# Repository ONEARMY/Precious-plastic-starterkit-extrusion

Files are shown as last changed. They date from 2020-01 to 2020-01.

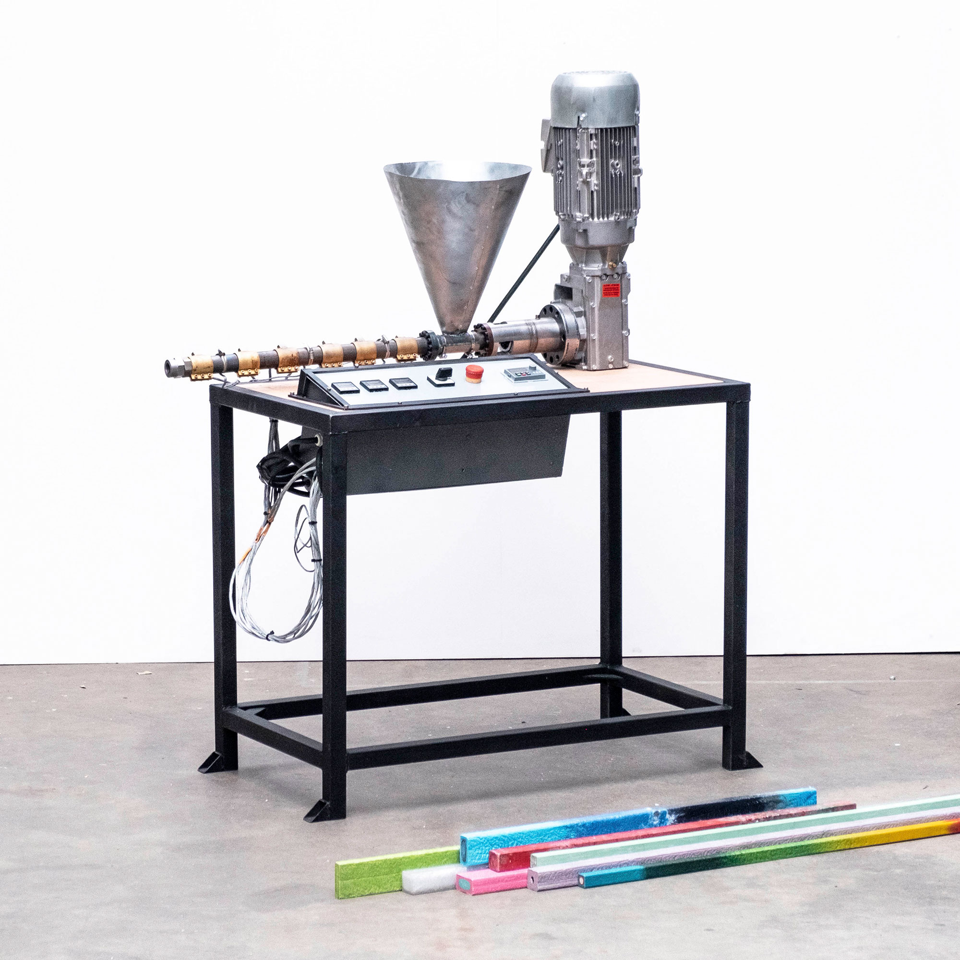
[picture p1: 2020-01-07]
3. Build the machine/Extrusion-Pro-image.jpg

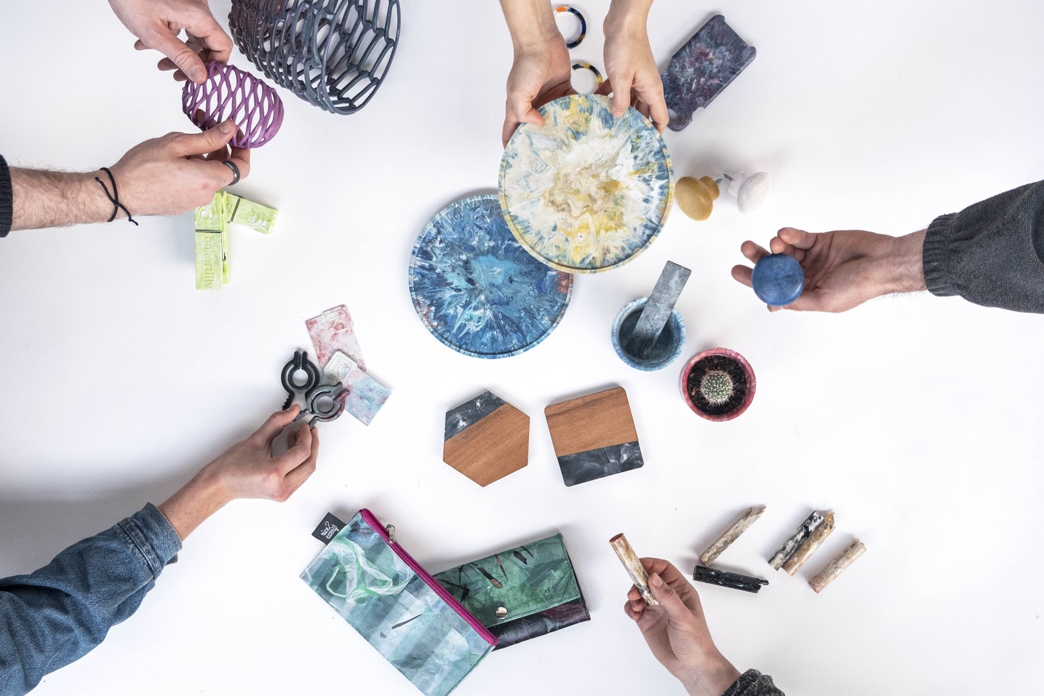
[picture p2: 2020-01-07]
6. Run your Workspace/3. Share/2. Project Images/Products/Products.jpg

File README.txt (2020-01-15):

# Starterkit - Extrusion Workspace V1.1

YEAH, you made it into a starter-kit!
Start with the 0. Start folder.. read the introduction text and make sure to watch the videos from our website.

If you have any questions visit our community platform or Discord
https://community.preciousplastic.com/
https://discordapp.com/invite/rnx7m4t

Good luck!!

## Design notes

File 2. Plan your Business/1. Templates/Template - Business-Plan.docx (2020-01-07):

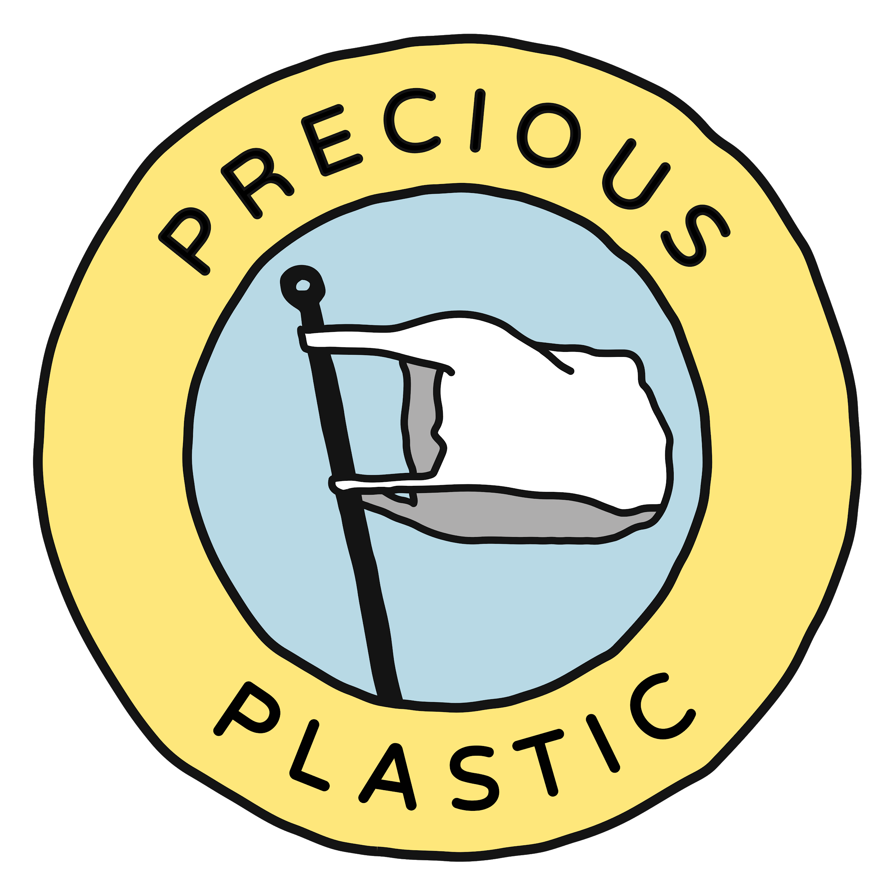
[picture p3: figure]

Your Logo and Business Name Here 👆

# Contact Details

Contact name:

Address:

City:

Zip:

Email:

Phone Number:

Website URL :

# Outline

1. Executive summary
2. Mission
3. Team
4. Market Analysis
  a. Product and Services
  b. Target Groups
  c. Engagement
  d. Sales Channels
5. Operations
  a. Key Resources
  b. Key Activities
  c. Running Costs
  d. Collaborators
6. Impact Measures
  a. Community
  b. Planet
  c. Income Streams
7. Financials
8. Legal Structure
9. Appendix

# 1. Executive Summary

This is your chance to quickly make your argument of what the problem is and how your business is going to solve it. This section shouldn’t be more than a couple paragraphs. Quickly cover the problem, your unique solution, who you’re targeting, and what your impact will be. It’s best to write this section after you’ve completed the whole business plan.

# 2. Mission

What’s the problem?

It’s best to start off describing what problem you’re solving. If your audience might need some education about the plastic waste problem - here’s your chance. What part or aspect of the plastic waste problem are you focusing on? You can set some context about the global plastic waste issue, but make sure to drill down to your national and local level as well. Try to be specific and stress why this is such a big problem facing the planet and your local community. Show your passion for solving this problem. This section will set the stage for the whole story told throughout the plan.

What’s your solution?

Next briefly cover how your solution addresses this problem. For example, if you write about how the plastic waste problem is due to a lifestyle issue, maybe you’re solution is focused on educating people because it addresses the root cause of the problem.

What’s your mission statement?

Look back on your mission that you filled out in the action plan. How can you elaborate to explain it to your reader?

What’s your vision?

Once you have explained your mission - write just a few sentences about your vision. What kind of world do you envision, and what do you envision for your organization?

# 3. Team

Fill in some basic information about your team to show who’s involved and what relevant skills and experience they have to the business.

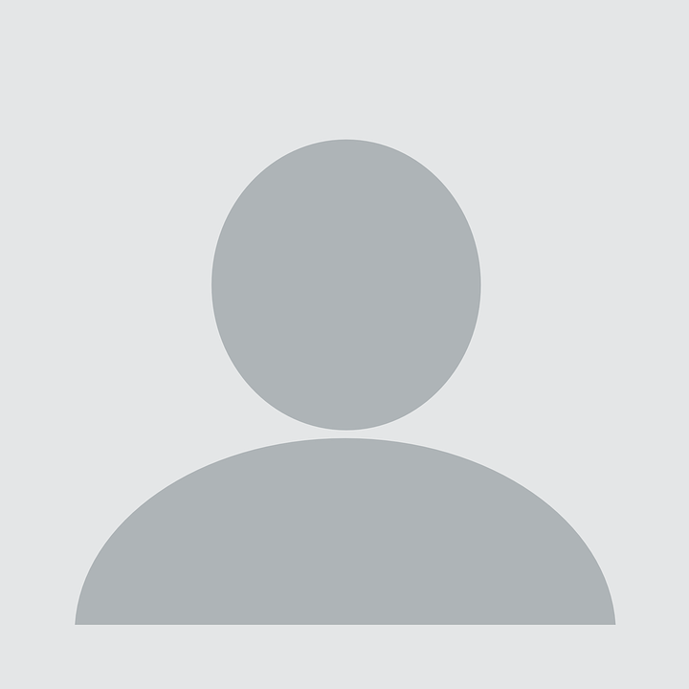
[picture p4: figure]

Name: Role: Experience: | Name: Role: Experience: | Name: Role: Experience:

# 4. Market Analysis

The market analysis section (broken down by the right side of the action plan), is where you will describe how the market is currently performing in your area of interest, how you plan to enter the market, what makes you different, who you are targeting, and how you will deliver your products and services to the customer.

## A. Products & Services

Product explanation

Explain that there is something missing from the market currently and what unique products or services you will offer to meet that unmet need. Write down a brief description of the products and services you are planning to make and include some pictures if possible. Include the price range they will be in and how this compares to similar products/services. If you have any sketches or pictures of your products, you can also include them here.

Product Photos or Sketches:

Competitive advantage

It’s unlikely that your product or service is completely unique - there are businesses or organizations that are probably doing something similar. What are those businesses, what are they offering, and how are you differentiating yourself? Another way to ask this what is your competitive advantage? What are you doing that sets you apart? Describe it here.

Total Available Market

What would you estimate to be the total available market for your product or service? For example, I’m targeting the plastic waste generated in my town, and I know from my city waste department that we generate about 100 tons per month of waste plastic. That means if we were to capture 100 % of the market, we would be processing all 100 tons. If we value each ton at $10, that a $12,000 total available market per year. You should include the total available market that you’re targeting to show how big your business could potentially grow.

## B. Target Groups

Identify the groups

In this section, explain who your target customer groups are, and how many potential customers are in this group. What do you know about these groups? This is your chance to communicate your research about your customers.

Research

What research have you done to show that your target groups will be interested in your products and services? Discuss any field research that you’ve done or online research about these groups. For example, if you’re producing craft furniture from plastic waste, do some research online to see if you can find numbers on the total craft furniture market value in your country. You could also run a small survey in your area to gauge interest in your products.

If you’re targeting businesses, do you have any letters of intent or proof that they are willing to buy your product or service when you’re able to get up and running? This can be a very powerful tool for showing your business case - you already have customers lining up to buy.

## C. Engagement

Engagement is how you will engage with your target customer groups and how many people you can potentially reach with this engagement strategy. What marketing channels are you using? If you’re using social media - which platforms? What’s your engagement rollout plan? Do you intend to start with one marketing channel and then gradually expand? Communicate your marketing plan here.

## D. Sales Channels

Finally, explain what your sales channels are. Explain where and how people can buy your products/services. Explain why you chose these sales channels, and relate that back to your target groups.

Business to Business (B to B) versus Business to Consumer (B to C)

Are you focusing on business to consumer or business to business? This is an important distinction, because it will help the reader understand your business model. Business to consumer (B to C) means that you are targeting consumers directly - you will be the one selling the product or service to the end user. If you are instead focusing on business to business (B to B), that means that you’ll be selling to other businesses. For example - if you’re a machine builder that will be selling machines to new workspaces - this is a business to business model. If you are a product producer selling products directly to people through the Precious Plastic Bazar, this is an example of business to consumer.

# 5. Operations

## A. Key Resources

First explain what key resources, or the key tools, machines, people, and any other resources that are crucial for you to deliver on your mission.

Another good thing to include here is any permits or licenses that you might need from the government in order to be able to operate. Are there any safety requirements that you need to follow? What resources do you need to have available in order to do so? What about people - are there any key skill sets that you need?

Include any pictures of your workspace if it’s relevant as well.

## B. Key Tasks

Explain your key tasks - What actions and activities will you need to focus on? Show that you have a clear sense of what needs to be done. How will produce your product or service and what are the key tasks that you must do to support this core delivery. Describe your production or service delivery process in detail and how you will maintain quality. How do you and your team’s skills and experience match up with these activities?

## C. Running Costs

In this section you will describe in more detail the key running costs that you identified in the Action Plan. Doesn’t need to be very long - this is just to show that you’ve thought about the costs that are a risk to the business month after month. If you have a way to control these costs, discuss that here as well.

## D. Collaborators

Finally, write about who your key collaborators are. What people, groups and organizations will be key in helping you fulfill your mission? Say what they will add to your business, and what your current relationship is with them. Are these people you would like to collaborate with, or you’ve already started? What’s the current status? How will they help you deliver on your mission? Be specific here - show what strategic relationships that you have which will be a strategic asset to your business.

# 6. Impacts

## A. Community

Here’s your chance to write about the positive impact you will have on your community. What’s the direct impact you will have on improving the lives of real people? Link this back to your mission and vision if possible.

You can also discuss your involvement with the Precious Plastic community. Perhaps discuss how you will contribute back to the Precious Plastic open source community and share your knowledge with other Precious Plastic workspaces.

## B. Planet

The planet section is for you to discuss the positive impact you will have on the environment. Show your vision and dream about a cleaner, greener future. It’s important to think about how you will measure this as well. For many Precious Plastic businesses this will be the amount of material recycled.

## C. Income Streams

Next describe your revenue model, or how you intend to bring in money month after month. Refer back to what you wrote in the action plan - is it product sales, workshop ticket sales, machine maintenance fees, or some other revenue model? How do you intend to price your products and services? Do you have different models for different products and services? Describe each one in detail.

# 7. Financials

The financials section is where you will build holistic financial picture to argue that you can turn your idea into a financially successful business.

First, write about the investment costs that you will have to pay in order to get started. You can pull this information from the workspace calculator and paste into a table. Copy in the investment costs table from the workspace calculator and add a total value.

Investment Costs
Initial Investments | Cost
Total:

Next describe how you intend to raise the initial money you need to get started. Is this a bank loan, grants, your private money, or assistance from the local government? Describe the different forms of financial assistance that you are pursuing.

Next you should copy in the Profit & Loss statement from the workspace calculator generated on the “extras” page. The profit and loss statement shows your estimated financial outlook for the first three years of operation.

Profit and Loss Statement
| Year 1 | Year 2 | Year 3
Revenue
Cost of Sales
Net Revenue
Fixed Costs
Gross Income from Operations
Business Taxes
Net Income

The cash flow statement shows that you will have enough money on hand to meet your financial obligations throughout the first year. Grants or bank loan applications often ask for these statements.

Cash Flow Statement
Month
Money In Bank (Beginning of Month)
Initial Investment
Revenue
Total Cash In
Investment Costs
Variable Costs
Fixed Costs
Total Cash Out
Net Cash Flow
Money In Bank (End of Month)

8. Legal Structure

The legal structure section is where to describe how you’ll be organized as a legal entity, or how you’re registered with the government. Your project doesn’t need to be structured as a commercial business - could be a non-profit, association, cooperative, project within an existing business, B - corp, social business. “Business plan” is the terminology that’s often used for a plan such as this, but doesn’t mean you need to run it necessarily as a “for-profit” business. This is going to depend on your situation, and could also depend on your country - sometimes it’s easier to structure a project a certain way depending on the legal entity regulations. One or the other maybe more tax friendly - more often a non-for profit or association is the more favorable tax structure for receiving grants. Describe here which legal structure you intend to use and why.

# 9. Appendix

The appendix is the place at the end of your business plan for any other supporting documents, pictures, graphs, or anything else you can think of that will help build your case. You can refer to items in the appendix throughout your document. Some items that could be found here are signed letters of intent from businesses wanting to buy your product, extra pictures of your products or services, additional financial graphs, and letters of understanding between you and collaborators.

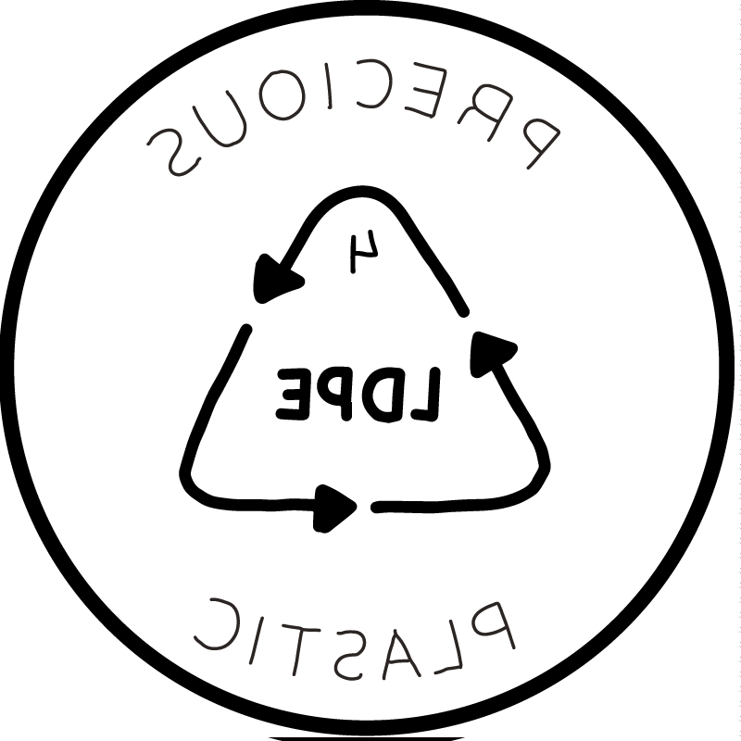
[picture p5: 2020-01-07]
6. Run your Workspace/1. Plastic Type Stamps/Stamps/LDPE.png

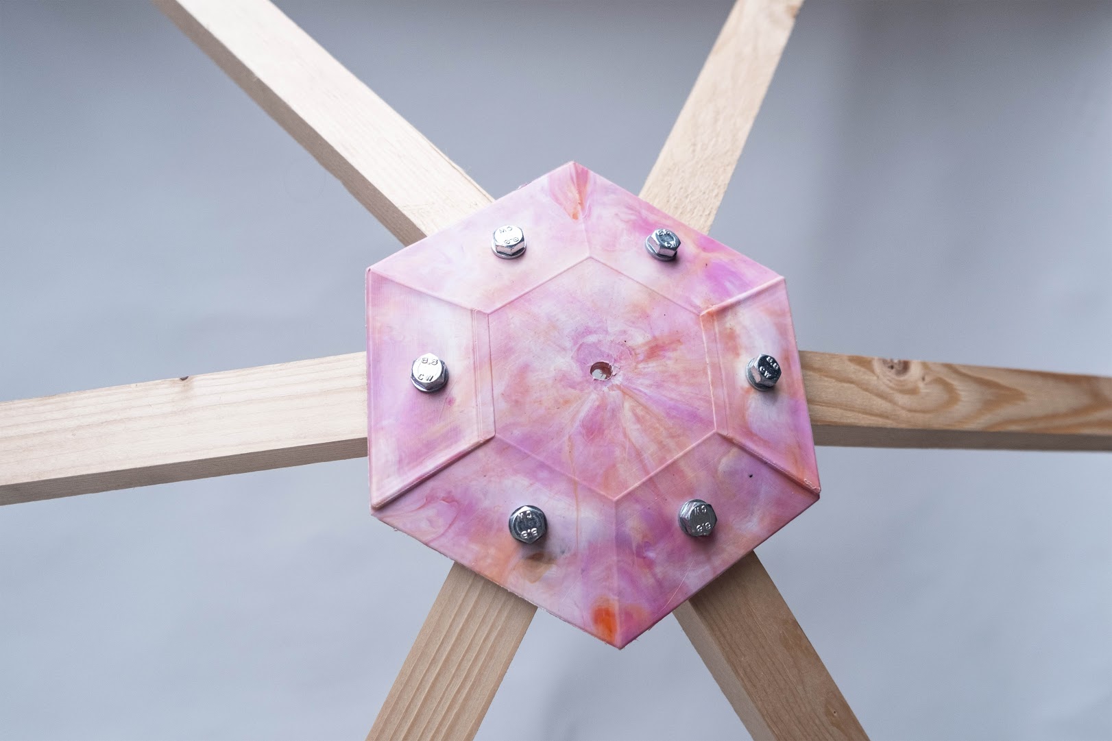
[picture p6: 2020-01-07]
6. Run your Workspace/3. Share/2. Project Images/Products/Dome-Close.jpg

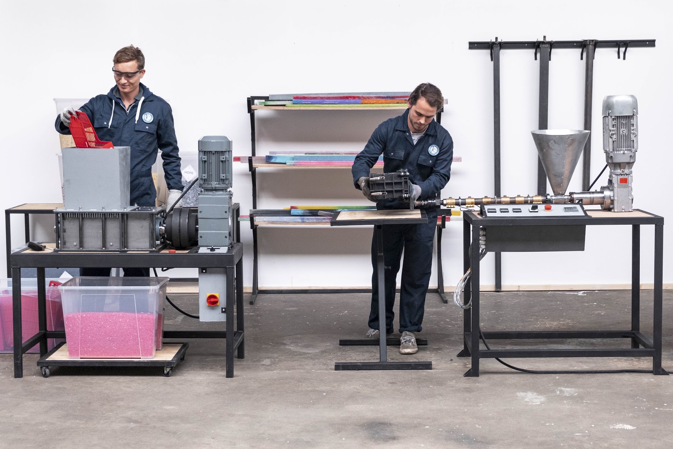
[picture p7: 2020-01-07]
6. Run your Workspace/3. Share/2. Project Images/At Work/Shreddier-and-Extrusion.jpg

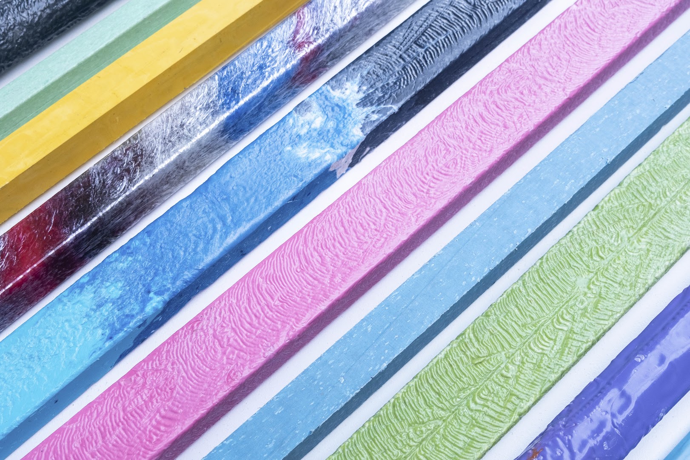
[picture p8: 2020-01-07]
6. Run your Workspace/3. Share/2. Project Images/Products/Beams.jpg

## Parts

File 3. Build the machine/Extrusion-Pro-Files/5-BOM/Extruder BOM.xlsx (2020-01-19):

Type | Item | Qty. | URL (Europe) | Price | Part/Assembly Number | Notes
Beams and Sheets | Hexagon stock Ø41 mm S235JR | 0.1 m | https://www.hattemleeuw.nl/ | €75.15 | EXTPRO-V1 1100.01, EXTPRO-V1 1140.03 | Ordered per 3 meter
Beams and Sheets | Seamless tube stock Ø40 x 5 mm, DIN 2391, S235JR | 0.75 m | https://www.hattemleeuw.nl/ | €36.00 | EXTPRO-V1 1130.01, EXTPRO-V1 1140.01, EXTPRO-V1 1200.01, EXTPRO-V1 1200.02 | Ordered per 6 meter
Beams and Sheets | Thick walled tube Ø82,5X22,2 mm S355J2H | 0.3 m | https://www.hattemleeuw.nl/ | €85.00 | EXTPRO-V1 1121.01, EXTPRO-V1 1121.02, EXTPRO-V1 1130.02 | Ordered per meter
Beams and Sheets | Tube Ø139,7X3,7 mm S355J2H | 0.03 m | https://www.hattemleeuw.nl/ | €10.00 | EXTPRO-V1 1110.01 | Ordered per meter
Beams and Sheets | Round rod stock Ø60 mm, 42CrMo4 (or C45) | 0.36 m | https://shop.kloeckner.fr/ | €38.83 | EXTPRO-V1 1120.01, EXTPRO-V1 1120.02 | Ordered per 6 meter
Beams and Sheets | Laser cut part : hinges, flanges, electronic box | 1 | https://www.247tailorsteel.com/nl | €81.50 | EXTPRO-V1-1110.02_A, EXTPRO-V1-1110.03_A, EXTPRO-V1-1130.03_A, EXTPRO-V1-1140.02_A EXTPRO-V1-2100.01_A, EXTPRO-V1-2100.02_A, EXTPRO-V1-2100.03_A, EXTPRO-V1-2100.04_A, EXTPRO-V1-2100.05_A, EXTPRO-V1-2100.06_A, EXTPRO-V1-3000.04_A, EXTPRO-V1-3000.05_A,
Beams and Sheets | Square tube steel 40 x 40 x 2.6 | 2 | https://www.danielsmetalen.nl/prijslijst_constructiestalen_plaatmaterialen.pdf#page=1 | €24.00 | EXTPRO-V1 3000.01 | (By 6 meters)
Beams and Sheets | L angle steel 25 x 25 x 3 mm | 1 | https://www.danielsmetalen.nl/prijslijst_constructiestalen_plaatmaterialen.pdf#page=1 | €6.26 | EXTPRO-V1 2000.01, EXTPRO-V1 3000.01 | (By 6 meters)
Beams and Sheets | Flat steel Bar 25 x 5 mm | 1 | https://www.danielsmetalen.nl/prijslijst_constructiestalen_plaatmaterialen.pdf#page=1 | €5.25 | EXTPRO-V1 3000.01 | (By 6 meters)
Beams and Sheets | Metal sheet 2000 x 1000 x 0,5 mm | 1 | https://www.danielsmetalen.nl/prijslijst_constructiestalen_plaatmaterialen.pdf#page=1 | €12.50 | EXTPRO-V1 1200.04
Beams and Sheets | Plywood Sheet | 1 | https://www.hornbach.nl/shop/Multiplexplaat-Powerplex-Pure-interieur-2440-x-1220-x-15-mm/8492344/artikel.html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 | €39.99 | EXTPRO-V1 3000.02, EXTPRO-V1 3000.03
Fastners | M8 x 45 Socket head screw | 4 | https://shop.eriks.nl/en/fasteners-bolts-socket-head-cap-screws-fillister-head-screws/din912-hex-socket-head-cap-screw-steel-8-8-zinc-plated-m8x45mm-23241231/ | €0.80 | EXTPRO-V1 30
Fastners | M8 x 25 Socket head screw | 6 | https://shop.eriks.nl/en/fasteners-bolts-socket-head-cap-screws-fillister-head-screws/din912-hex-socket-head-cap-screw-steel-8-8-zinc-plated-pr-ec002356-0008-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 | €0.78 | EXTPRO-V1 09
Fastners | M6 x 60 Socket head screw | 2 | https://shop.eriks.nl/en/fasteners-bolts-socket-head-cap-screws-fillister-head-screws/din912-hex-socket-head-cap-screw-steel-8-8-zinc-plated-pr-ec002356-0008-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 | €0.26 | EXTPRO-V1 27
Fastners | M6 x 35 Socket head screw | 4 | https://shop.eriks.nl/en/fasteners-bolts-socket-head-cap-screws-fillister-head-screws/din912-hex-socket-head-cap-screw-steel-8-8-zinc-plated-m6x35mm-23241210/ | €0.36 | EXTPRO-V1 32
Fastners | M6 x 20 Socket head screw | 12 | https://shop.eriks.nl/en/fasteners-bolts-socket-head-cap-screws-fillister-head-screws/din912-hex-socket-head-cap-screw-steel-8-8-zinc-plated-yellow-passivated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 | €0.84 | EXTPRO-V1 07
Fastners | M6 x 16 Socket head screw | 20 | https://shop.eriks.nl/en/fasteners-bolts-socket-head-cap-screws-fillister-head-screws/din912-hex-socket-head-cap-screw-steel-8-8-zinc-plated-m6x16mm-23241204/ | €1.20 | EXTPRO-V1 08
Fastners | M6 x 10 Socket head screw | 4 | https://shop.eriks.nl/en/fasteners-bolts-socket-head-cap-screws-fillister-head-screws/din912-hex-socket-head-cap-screw-steel-8-8-zinc-plated-m6x10mm-23241202/ | €0.20 | EXTPRO-V1 15
Fastners | M5 x 16 Socket head screw | 6 | https://shop.eriks.nl/en/fasteners-bolts-socket-head-cap-screws-fillister-head-screws/din912-hex-socket-head-cap-screw-steel-8-8-zinc-plated-m5x16mm-23241188/ | €0.24 | EXTPRO-V1 25
Fastners | M8 Nuts | 4 | https://shop.eriks.nl/en/fasteners-nuts-hexagonal-full-nuts/hex-nut-din934-steel-10-9-m8-23238449/ | €0.24 | EXTPRO-V1 31
Fastners | M6 Nuts | 4 | https://shop.eriks.nl/en/fasteners-nuts-hexagonal-full-nuts/hex-nut-din934-steel-10-9-m6-23238448/ | €0.24 | EXTPRO-V1 28
Fastners | M5 Nuts | 6 | https://shop.eriks.nl/en/fasteners-nuts-hexagonal-full-nuts/hex-nut-din934-steel-10-9-m5-23238447/ | €0.36 | EXTPRO-V1 14
Fastners | M8 washers | 4 | https://shop.eriks.nl/en/fasteners-washers-plain-washers/flat-washer-steel-din-125-m8-23256064/ | €0.08 | EXTPRO-V1 29
Fastners | M6 Washers | 8 | https://shop.eriks.nl/en/fasteners-washers-plain-washers/flat-washer-steel-electrolytic-zinc-plated-din-125-m6-23256090/ | €0.08 | EXTPRO-V1 26
Motor | Motorreductor Siemens BAZ39-LE100ZLSB4P | 1 | https://www.koster-elektromotoren.nl/ | €912.00 | EXTPRO-V1 01 | Hollow shaft Ø30 + Key way
Electronics | Inverter drive | 1 | https://nl.rs-online.com/web/p/inverter-drives/1756234/ | €454.16 | EXTPRO-V1 17, EXTPRO-V1 22
Electronics | Control cable for inverter drive | 1 | https://nl.rs-online.com/web/p/inverter-drives/1756249/ | €14.40 | NA
Electronics | PID Controller | 3 | https://www.amazon.de/Digitaler-Temperaturregler-REX-C100-Thermostat-Relaisausgang/dp/B078M7GCDK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 | €20.23 | EXTPRO-V1 16
Electronics | SSR Heatsink | 3 | https://www.amazon.de/easycargo-Aluminium-K%C3%BChlk%C3%B6rper-Heizk%C3%B6rper-80-mmx50mmx50/dp/B07B3Y2ZNY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 | €29.97 | EXTPRO-V1 19
Electronics | 40A SSR | 3 | https://www.amazon.de/KKmoon-24V-380V-SSR-40-Relaismodul-Temperaturregler/dp/B010Q6898C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 | €26.97 | EXTPRO-V1 18
Electronics | Emergency Stop | 1 | https://nl.rs-online.com/web/p/emergency-stop-push-buttons/1682546/ | €15.78 | EXTPRO-V1 21
Electronics | Button On/Off | 1 | https://nl.rs-online.com/web/p/rotary-cam-switches/0332133/ | €18.78 | EXTPRO-V1 20
Electronics | M20 Cable Gland | 1 | https://nl.rs-online.com/web/p/cable-glands/6694660/ | €4.57 | EXTPRO-V1 24 | Bag of 5 pieces
Electronics | M16 Cable Gland | 2 | https://nl.rs-online.com/web/p/cable-glands/6694667/ | €11.79 | EXTPRO-V1 23 | Bag of 5 pieces
Electronics | 12A Contactor | 1 | https://nl.rs-online.com/web/p/contactors/4930129/ | €51.87 | NA
Electronics | 16A Male Plug | 1 | https://www.hornbach.nl/shop/PCE-CEE-Fase-inverter-16A/828911/artikel.html | €9.50 | NA | If no plug included with the motor
Electronics | H07 5 Multi-core Cable (6mm) | 1 | https://www.neopreen-kabel.nl/5-aderige-neopreenkabel/24-5-x-25-mm2-neopreenkabel-tm-99-meter.html | €24.20 | NA | (For 5 meter) If no Multi-core Cable included with the motor
Electronics | Electric Splicing Connector | 1 | https://www.amazon.fr/Wago-Blister-panach%C3%A9-connexion-automatique/dp/B06XRHV7VJ?s=hi | €9.90 | NA
Electronics | Heating element Ø40 x 20mm 350W Type 4 | 1 | https://webshop.rokoma.com/?p=p&i=172 | €27.58 | EXTPRO-V1 11 | (1 Meter cable)
Electronics | Heating element Ø40 x 50mm 350W Type 4 | 5 | https://webshop.rokoma.com/?p=p&i=172 | €200.73 | EXTPRO-V1 13 | (1 Meter cable)
Electronics | Thermocouple collar | 3 | https://www.tcdirect.nl/Default.aspx?level=2&department_id=180/26 | €78.03 | EXTPRO-V1 12
Misc. | Extrusion screw - D=30 L=600 | 1 | https://zswxlg.en.alibaba.com/?spm=a2700.8443308.0.0.13dc2364vILPmG | €300.00 | EXTPRO-V1 1100.02-A | Price with bulk
Misc. | Ammlock ALK 142 / 20 x 47 | 1 | https://www.atd.nl/klembus-ammlock-p-22279.html | €19.80 | NA
Misc. | Taper roller bearing | 2 | https://shop.eriks.nl/nl/lagers-kegellagers-kegellagers-metrisch/eenrijig-kegellager-32006-x-q-23756738/ | €27.78 | EXTPRO-V1 04
Misc. | Radial shaft seal | 2 | https://shop.eriks.nl/nl/afdichtingstechniek-asafdichtingen-oliekeerringen/oliekeerring-nbr-r-42x55x8-10006078/ | € 7,10 | EXTPRO-V1 02
Misc. | Shaft Collar Ø30 | 1 | https://nl.rs-online.com/web/p/collars/1746739/ | €15.15 | EXTPRO-V1 03
Misc. | Worm drive clamp 50 mm | 2 | https://nl.rs-online.com/web/p/hose-clips-jubilee-clips/0525278/ | €1.28 | EXTPRO-V1 10 | Bag of 5 pieces
Misc. | Iron Fitting Plain Plug, 1/4 | 1 | https://nl.rs-online.com/web/p/malleable-iron-fittings/2435177/?searchHistory=%7B%22enabled%22%3Atrue%7D | €6.13 | NA | Bag of 10 pieces
Misc. | Isolant cork gasket | 1 | https://www.techniekwebshop.nl/reinz-rubb-kurkpakking-914x914x2-mm-703122200-2-mm-914-mm-914-mm.html | €40.96 | EXTPRO-V1 1200.03-A
 |  |  | Total: | €2741.72

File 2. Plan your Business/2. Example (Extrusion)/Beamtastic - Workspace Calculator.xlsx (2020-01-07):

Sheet: Read Me!
Precious Plastic Workspace Calculator
 | Welcome to the Precious Plastic Workspace Calculator! This tool will help you understand the numbers behind starting a Precious Plastic business.
You will learn:
- How much money you need to start your workspace
- How long it will take to pay back your intitial investment
- What prices for your products will cover the costs of production
Before you get started:
1. Only fill in cells that are bordered in blue
2. Get started by clicking on the sales tab below
 |  | Cells where you should enter numbers
 |  | Cells with numbers we calculate for you
 |  | If you click cells with red arrows, more information pops up

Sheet: 1. Sales
Sales
In the first column, list all the products, machines, workshops or services that you plan on selling with your Precious Plastic workspace. In the second column, estimate how much each product or service would cost you in materials. In the third column, estimate the time it will take to create each product or service.
Products or Services | Material Cost for Each Product | Number of Working Hours to Produce Each Product or Service
Long Beams (2 m) | 6.00 | 0.30
Medium Beams (1.5 m) | 4.50 | 0.21
Short Beams (0.7 m) | 2.10 | 0.13

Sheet: 2. Costs
Working Hours |  | Investment Costs |  | Fixed Costs
Besides making products & services, you will have to spend time on doing other tasks. In this section, fill in your weekly activities and how many hours you will spend on each activity per week. Do not include the time to directly produce products or services. |  | These are the machines, tools, and other expenses you need to set up your workspace. These costs are also known as your "investment costs" and are only paid once. |  | Fixed costs are the costs that do not vary with the amount of products and services that you produce, but you have to pay on a regular basis. Some costs may need to be paid quarterly or yearly, so do some quick calculations to estimate them on a monthly basis.
Weekly Activities | Hours per Week | Initial Investments | Cost | Fixed Costs | Cost per Month
Logistic and Plastic Sourcing | 5.0 | Extruder Pro | 5500.00 | Rent | 350.00
Administration | 10.0 | 3 Long Moulds (2 m x 41 mm x 41mm) | 21.00 | Water | 30.00
Distribution | 6.0 | 3 Medium Moulds (1.5 m x 41 mm x 41mm) | 16.00 | Electricity | 45.00
Marteking and B2B relationship | 7.0 | 3 Short Moulds (0.7 m x 41mm x 41mm) | 8.00 | Gas | 70.00
Sales | 8.0 | Business license and permits | 300.00 | Internet | 40.00
Machine Maintenance | 5.0 | Workspace Renovation | 950.00 | Insurance | 60.00
Cleaning Workspace | 7.0 | Coffee Machine | 20.00 | Office Snacks/Lunch | 110.00
Preparing Extruder to Extrude | 5.0 | First Aid Kit | 30.00 | Car Insurance/Maintenance | 80.00
 |  | Office Supplies | 100.00 | Website Service | 20.00
 |  | Computer | 300.00 | Office Supplies | 30.00
 |  | Speaker | 25.00
 |  | Van | 2000.00
 |  | Table | 100.00
 |  | Chairs | 150.00
 |  | Safety Kit | 70.00
 |  | Beams containers | 140.00
 |  | Ventilation System (Fan, Filter and ducting) | 130.00
 |  | Shredded plastic storage shelf | 15.00
 |  | Workbench | 30.00
 |  | Shredded plastic trolley | 15.00
 |  | Mobile tool station | 10.00
 |  | Beam storage racks | 5.00
 |  | Beam mould hanger | 10.00
 |  | Adjustable mould support surface | 15.00
 |  | Ventilation caddy | 100.00
 |  | Offcut bucket | 5.00
 |  | Scoop | 5.00
 |  | Screwdriver | 2.00
 |  | Vise | 40.00
 |  | Channel lock pliers | 8.00
 |  | Putty knife | 3.00
 |  | Allen keys | 5.00
 |  | Wrenches | 25.00
 |  | Hammer | 10.00
 |  | Heat-resistant gloves | 15.00
 |  | Safety glasses | 5.00
 |  | Filter mask | 50.00
 |  | Chisel | 10.00
 |  | Drill | 40.00

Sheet: 3. Dashboard
Dashboard | Sales Overview |  |  |  |  | Wages
 | Products & Services | Selling Price Per Unit | Number of Expected Sales Per Month | Total Product Cost | Profit Margin | Hourly Wage | 8.00
Start by entering your desired hourly wage, selling prices, and expected sales for each product. Then play around with your pricing, hourly wage, and expected sales to see how it affects the time needed to pay back your investment, monthly profit, and monthly pay. Make sure you set prices for your products and services so that the numbers in the profit margin column turn green, which means you are covering the costs of producing them. | Long Beams (2 m) | 22.00 | 100.0 | 19.51 | 12.74% |  | 3 | *
 | Medium Beams (1.5 m) | 16.00 | 120.0 | 13.96 | 14.62%
 | Short Beams (0.7 m) | 10.00 | 130.0 | 7.96 | 25.69% | Summary
 |  |  |  |  |  | Money Needed to Start | 14943.72
 |  |  |  |  |  | Months to Pay Back Investment | 21
 |  |  |  |  |  | Full Time Employees Needed | 1.8
 |  |  |  |  |  | Revenue Earned Per Month | 5420.00
 |  |  |  |  |  | Fixed Costs Per Month | 835.00
 |  |  |  |  |  | Material Costs Per Month | 1413.00
 |  |  |  |  |  | Total Wages Paid Per Month | 2412.72
 |  |  |  |  |  | Total Profit Earned Per Month | 759.28

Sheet: Extras
Extras
This page provides you with some basic finanial statements (Cashflow and Profit & Loss) and shows you the calculations from the previous pages. It's more for those people who want to dive deep into the numbers or provide a bank with forecasted financial statements.
Cash Flow A cash flow analysis shows that you have enough money throughout your first year to buy materials, pay your employees, or make an investment into a new machine.
 | Month 1 | Month 2 | Month 3 | Month 4 | Month 5 | Month 6 | Month 7 | Month 8 | Month 9 | Month 10 | Month 11 | Month 12
Money In Bank (Beginning of Month) | 14943.72 | 7255.92 | 9851.12 | 12446.32 | 15041.52 | 17636.72 | 20231.92 | 22827.12 | 25422.32 | 28017.52 | 30612.72 | 33207.92
Initial Investment | 14943.72
Revenue | 5420.00 | 5420.00 | 5420.00 | 5420.00 | 5420.00 | 5420.00 | 5420.00 | 5420.00 | 5420.00 | 5420.00 | 5420.00 | 5420.00
Total Cash In | 20363.72 | 5420.00 | 5420.00 | 5420.00 | 5420.00 | 5420.00 | 5420.00 | 5420.00 | 5420.00 | 5420.00 | 5420.00 | 5420.00
Investment Costs | -10283.00
Variable Costs | -1989.80 | -1989.80 | -1989.80 | -1989.80 | -1989.80 | -1989.80 | -1989.80 | -1989.80 | -1989.80 | -1989.80 | -1989.80 | -1989.80
Fixed Costs | -835.00 | -835.00 | -835.00 | -835.00 | -835.00 | -835.00 | -835.00 | -835.00 | -835.00 | -835.00 | -835.00 | -835.00
Total Cash Out | -13107.80 | -2824.80 | -2824.80 | -2824.80 | -2824.80 | -2824.80 | -2824.80 | -2824.80 | -2824.80 | -2824.80 | -2824.80 | -2824.80
Net Cashflow | 7255.92 | 2595.20 | 2595.20 | 2595.20 | 2595.20 | 2595.20 | 2595.20 | 2595.20 | 2595.20 | 2595.20 | 2595.20 | 2595.20
Money In Bank (End of Month) | 7255.92 | 9851.12 | 12446.32 | 15041.52 | 17636.72 | 20231.92 | 22827.12 | 25422.32 | 28017.52 | 30612.72 | 33207.92 | 35803.12
Profit and Loss This table is to show how much money the company is projected to make each year. It assumes that you paid yourself for the hours you worked, so the "Net Income" at the bottom is the remaining profit made by your company. It is greatly influenced by the "Monthly Sales Improvement Rate" on the Dashboard page. This table is also useful to show your bank or include in grant applications.
 | Year 1 | Year 2 | Year 3 |  | Yearly Growth Rate
Revenue | 65040.00 | 71544.00 | 78698.40 |  | Low
Cost of Sales | 23877.60 | 26265.36 | 28891.90 |  | 0.10 €
Net Revenue | 41162.40 | 45278.64 | 49806.50
Fixed Costs | 10020.00 | 10020.00 | 10020.00
Gross Income from Operations | 31142.40 | 35258.64 | 39786.50
 |  |  |  |  | Business Tax Rate (Research for your Country)
Business Taxes | 6228.48 | 7051.73 | 7957.30 |  | 20.00%
Net Income | 24913.92 | 28206.91 | 31829.20
Monthly Sales Figures
Products and Services | Revenue | Overhead Cost | Indirect Labor Cost | Production Labor Cost | Material Cost | Total Monthly Cost | Total Monthly Profit | Total Monthly Hours
Long Beams (2 m) | 2200.00 |  |  |  |  |  | 248.66 | 30.00
 |  | 347.43 | 763.91 | 240.00 | 600.00 | 1951.34
Medium Beams (1.5 m) | 1920.00 |  |  |  |  |  | 244.87 | 25.20
 |  | 291.84 | 641.68 | 201.60 | 540.00 | 1675.13
Short Beams (0.7 m) | 1300.00 |  |  |  |  |  | 265.75 | 16.90
 |  | 195.72 | 430.33 | 135.20 | 273.00 | 1034.25
Total Revenue | 5420.00 |  |  |  |  |  | #VALUE!
Total Cost |  | 835.00 | 1835.92 | 576.80 | 1413.00 | 4660.72 |  | 72.10
Payback Table
Don't worry too much about this one, it's just to make the payback analysis graph on the dashboard | 0 | 0 | 0 | 0 | 0 | 0 | 0 | 0 | 0 | 0 | 0 | 0 | 0 | 0 | 0 | 0 | 0 | 0 | 0 | 0 | 1 | 1 | 1 | 1 | 1 | 1 | 1 | 1 | 1 | 1 | 1 | 1 | 1 | 1 | 1 | 1
Month | 1 | 2 | 3 | 4 | 5 | 6 | 7 | 8 | 9 | 10 | 11 | 12 | 13 | 14 | 15 | 16 | 17 | 18 | 19 | 20 | 21 | 22 | 23 | 24 | 25 | 26 | 27 | 28 | 29 | 30 | 31 | 32 | 33 | 34 | 35 | 36
Money You Invested | -14943.72 | -14184.44 | -13425.16 | -12665.88 | -11906.60 | -11147.32 | -10388.04 | -9628.76 | -8869.48 | -8110.20 | -7350.92 | -6591.64 | -5832.36 | -5073.08 | -4313.80 | -3554.52 | -2795.24 | -2035.96 | -1276.68 | -517.40 | 241.88 | 1001.16 | 1760.44 | 2519.72 | 3279.00 | 4038.28 | 4797.56 | 5556.84 | 6316.12 | 7075.40 | 7834.68 | 8593.96 | 9353.24 | 10112.52 | 10871.80 | 11631.08
Money You Invested (+) | 0.00 | 0.00 | 0.00 | 0.00 | 0.00 | 0.00 | 0.00 | 0.00 | 0.00 | 0.00 | 0.00 | 0.00 | 0.00 | 0.00 | 0.00 | 0.00 | 0.00 | 0.00 | 0.00 | 0.00 | 241.88 | 1001.16 | 1760.44 | 2519.72 | 3279.00 | 4038.28 | 4797.56 | 5556.84 | 6316.12 | 7075.40 | 7834.68 | 8593.96 | 9353.24 | 10112.52 | 10871.80 | 11631.08
Money You Invested (-) | -14943.72 | -14184.44 | -13425.16 | -12665.88 | -11906.60 | -11147.32 | -10388.04 | -9628.76 | -8869.48 | -8110.20 | -7350.92 | -6591.64 | -5832.36 | -5073.08 | -4313.80 | -3554.52 | -2795.24 | -2035.96 | -1276.68 | -517.40 | 0.00 | 0.00 | 0.00 | 0.00 | 0.00 | 0.00 | 0.00 | 0.00 | 0.00 | 0.00 | 0.00 | 0.00 | 0.00 | 0.00 | 0.00 | 0.00
Revenue | 5420.00 | 5420.00 | 5420.00 | 5420.00 | 5420.00 | 5420.00 | 5420.00 | 5420.00 | 5420.00 | 5420.00 | 5420.00 | 5420.00 | 5420.00 | 5420.00 | 5420.00 | 5420.00 | 5420.00 | 5420.00 | 5420.00 | 5420.00 | 5420.00 | 5420.00 | 5420.00 | 5420.00 | 5420.00 | 5420.00 | 5420.00 | 5420.00 | 5420.00 | 5420.00 | 5420.00 | 5420.00 | 5420.00 | 5420.00 | 5420.00 | 5420.00
Variable Cost | 1989.80 | 1989.80 | 1989.80 | 1989.80 | 1989.80 | 1989.80 | 1989.80 | 1989.80 | 1989.80 | 1989.80 | 1989.80 | 1989.80 | 1989.80 | 1989.80 | 1989.80 | 1989.80 | 1989.80 | 1989.80 | 1989.80 | 1989.80 | 1989.80 | 1989.80 | 1989.80 | 1989.80 | 1989.80 | 1989.80 | 1989.80 | 1989.80 | 1989.80 | 1989.80 | 1989.80 | 1989.80 | 1989.80 | 1989.80 | 1989.80 | 1989.80
Fixed Cost | 2670.92 | 2670.92 | 2670.92 | 2670.92 | 2670.92 | 2670.92 | 2670.92 | 2670.92 | 2670.92 | 2670.92 | 2670.92 | 2670.92 | 2670.92 | 2670.92 | 2670.92 | 2670.92 | 2670.92 | 2670.92 | 2670.92 | 2670.92 | 2670.92 | 2670.92 | 2670.92 | 2670.92 | 2670.92 | 2670.92 | 2670.92 | 2670.92 | 2670.92 | 2670.92 | 2670.92 | 2670.92 | 2670.92 | 2670.92 | 2670.92 | 2670.92
Net Profit | 759.28 | 759.28 | 759.28 | 759.28 | 759.28 | 759.28 | 759.28 | 759.28 | 759.28 | 759.28 | 759.28 | 759.28 | 759.28 | 759.28 | 759.28 | 759.28 | 759.28 | 759.28 | 759.28 | 759.28 | 759.28 | 759.28 | 759.28 | 759.28 | 759.28 | 759.28 | 759.28 | 759.28 | 759.28 | 759.28 | 759.28 | 759.28 | 759.28 | 759.28 | 759.28 | 759.28

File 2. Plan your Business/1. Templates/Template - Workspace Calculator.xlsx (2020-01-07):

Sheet: Read Me!
Precious Plastic Workspace Calculator
 | Welcome to the Precious Plastic Workspace Calculator! This tool will help you understand the numbers behind starting a Precious Plastic business.
You will learn:
- How much money you need to start your workspace
- How long it will take to pay back your intitial investment
- What prices for your products will cover the costs of production
Before you get started:
1. Only fill in cells that are bordered in blue
2. Get started by clicking on the sales tab below
 |  | Cells where you should enter numbers
 |  | Cells with numbers we calculate for you
 |  | If you click cells with red arrows, more information pops up

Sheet: 1. Sales
Sales
In the first column, list all the products, machines, workshops or services that you plan on selling with your Precious Plastic workspace. In the second column, estimate how much each product or service would cost you in materials. In the third column, estimate the time it will take to create each product or service.
Products or Services | Material Cost for Each Product | Number of Working Hours to Produce Each Product or Service

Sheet: 2. Costs
Working Hours |  | Investment Costs |  | Fixed Costs
Besides making products & services, you will have to spend time on doing other tasks. In this section, fill in your weekly activities and how many hours you will spend on each activity per week. Do not include the time to directly produce products or services. |  | These are the machines, tools, and other expenses you need to set up your workspace. These costs are also known as your "investment costs" and are only paid once. |  | Fixed costs are the costs that do not vary with the amount of products and services that you produce, but you have to pay on a regular basis. Some costs may need to be paid quarterly or yearly, so do some quick calculations to estimate them on a monthly basis.
Weekly Activities | Hours per Week | Initial Investments | Cost | Fixed Costs | Cost per Month

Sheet: 3. Dashboard
Dashboard | Sales Overview |  |  |  |  | Wages
 | Products & Services | Selling Price Per Unit | Number of Expected Sales Per Month | Total Product Cost | Profit Margin | Hourly Wage
Start by entering your desired hourly wage, selling prices, and expected sales for each product. Then play around with your pricing, hourly wage, and expected sales to see how it affects the time needed to pay back your investment, monthly profit, and monthly pay. Make sure you set prices for your products and services so that the numbers in the profit margin column turn green, which means you are covering the costs of producing them. |  |  |  |  |  |  | 3 | *
 |  |  |  |  |  | Summary
 |  |  |  |  |  | Money Needed to Start
 |  |  |  |  |  | Months to Pay Back Investment | Too Long!
 |  |  |  |  |  | Full Time Employees Needed | 0.0
 |  |  |  |  |  | Revenue Earned Per Month | 0.00
 |  |  |  |  |  | Fixed Costs Per Month | 0.00
 |  |  |  |  |  | Material Costs Per Month | 0.00
 |  |  |  |  |  | Total Wages Paid Per Month | 0.00
 |  |  |  |  |  | Total Profit Earned Per Month | 0

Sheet: Extras
Extras
This page provides you with some basic finanial statements (Cashflow and Profit & Loss) and shows you the calculations from the previous pages. It's more for those people who want to dive deep into the numbers or provide a bank with forecasted financial statements.
Cash Flow A cash flow analysis shows that you have enough money throughout your first year to buy materials, pay your employees, or make an investment into a new machine.
 | Month 1 | Month 2 | Month 3 | Month 4 | Month 5 | Month 6 | Month 7 | Month 8 | Month 9 | Month 10 | Month 11 | Month 12
Money In Bank (Beginning of Month) |  | 0.00 | 0.00 | 0.00 | 0.00 | 0.00 | 0.00 | 0.00 | 0.00 | 0.00 | 0.00 | 0.00
Initial Investment
Revenue | 0.00 | 0.00 | 0.00 | 0.00 | 0.00 | 0.00 | 0.00 | 0.00 | 0.00 | 0.00 | 0.00 | 0.00
Total Cash In | 0.00 | 0.00 | 0.00 | 0.00 | 0.00 | 0.00 | 0.00 | 0.00 | 0.00 | 0.00 | 0.00 | 0.00
Investment Costs | 0.00
Variable Costs | 0.00 | 0.00 | 0.00 | 0.00 | 0.00 | 0.00 | 0.00 | 0.00 | 0.00 | 0.00 | 0.00 | 0.00
Fixed Costs | 0.00 | 0.00 | 0.00 | 0.00 | 0.00 | 0.00 | 0.00 | 0.00 | 0.00 | 0.00 | 0.00 | 0.00
Total Cash Out | 0.00 | 0.00 | 0.00 | 0.00 | 0.00 | 0.00 | 0.00 | 0.00 | 0.00 | 0.00 | 0.00 | 0.00
Net Cashflow | 0.00 | 0.00 | 0.00 | 0.00 | 0.00 | 0.00 | 0.00 | 0.00 | 0.00 | 0.00 | 0.00 | 0.00
Money In Bank (End of Month) | 0.00 | 0.00 | 0.00 | 0.00 | 0.00 | 0.00 | 0.00 | 0.00 | 0.00 | 0.00 | 0.00 | 0.00
Profit and Loss This table is to show how much money the company is projected to make each year. It assumes that you paid yourself for the hours you worked, so the "Net Income" at the bottom is the remaining profit made by your company. It is greatly influenced by the "Monthly Sales Improvement Rate" on the Dashboard page. This table is also useful to show your bank or include in grant applications.
 | Year 1 | Year 2 | Year 3 |  | Yearly Growth Rate
Revenue | 0.00 | 0.00 | 0.00 |  | Low
Cost of Sales | 0.00 | 0.00 | 0.00 |  | 0.10 €
Net Revenue | 0.00 | 0.00 | 0.00
Fixed Costs | 0.00 | 0.00 | 0.00
Gross Income from Operations | 0.00 | 0.00 | 0.00
 |  |  |  |  | Business Tax Rate (Research for your Country)
Business Taxes | 0.00 | 0.00 | 0.00 |  | 20.00%
Net Income | 0.00 | 0.00 | 0.00
Monthly Sales Figures
Products and Services | Revenue | Overhead Cost | Indirect Labor Cost | Production Labor Cost | Material Cost | Total Monthly Cost | Total Monthly Profit | Total Monthly Hours
 |  |  |  |  |  |  | #VALUE! | 0.00
 |  | #DIV/0! | #DIV/0! |  |  | #DIV/0!
 |  |  |  |  |  |  | #VALUE! | 0.00
 |  | #DIV/0! | #DIV/0! |  |  | #DIV/0!
 |  |  |  |  |  |  | #VALUE! | 0.00
 |  | #DIV/0! | #DIV/0! |  |  | #DIV/0!
 |  |  |  |  |  |  | #VALUE! | 0.00
 |  | #DIV/0! | #DIV/0! |  |  | #DIV/0!
 |  |  |  |  |  |  | #VALUE! | 0.00
 |  | #DIV/0! | #DIV/0! |  |  | #DIV/0!
 |  |  |  |  |  |  | #VALUE! | 0.00
 |  | #DIV/0! | #DIV/0! |  |  | #DIV/0!
 |  |  |  |  |  |  | #VALUE! | 0.00
 |  | #DIV/0! | #DIV/0! |  |  | #DIV/0!
 |  |  |  |  |  |  | #VALUE! | 0.00
 |  | #DIV/0! | #DIV/0! |  |  | #DIV/0!
 |  |  |  |  |  |  | #VALUE! | 0.00
 |  | #DIV/0! | #DIV/0! |  |  | #DIV/0!
 |  |  |  |  |  |  | #VALUE! | 0.00
 |  | #DIV/0! | #DIV/0! |  |  | #DIV/0!
 |  |  |  |  |  |  | #VALUE! | 0.00
 |  | #DIV/0! | #DIV/0! |  |  | #DIV/0!
Total Revenue | 0.00 |  |  |  |  |  | #VALUE!
Total Cost |  | #DIV/0! | #DIV/0! | 0.00 | 0.00 | #DIV/0! |  | 0.00
Payback Table
Don't worry too much about this one, it's just to make the payback analysis graph on the dashboard | #DIV/0! | #DIV/0! | #DIV/0! | #DIV/0! | #DIV/0! | #DIV/0! | #DIV/0! | #DIV/0! | #DIV/0! | #DIV/0! | #DIV/0! | #DIV/0! | #DIV/0! | #DIV/0! | #DIV/0! | #DIV/0! | #DIV/0! | #DIV/0! | #DIV/0! | #DIV/0! | #DIV/0! | #DIV/0! | #DIV/0! | #DIV/0! | #DIV/0! | #DIV/0! | #DIV/0! | #DIV/0! | #DIV/0! | #DIV/0! | #DIV/0! | #DIV/0! | #DIV/0! | #DIV/0! | #DIV/0! | #DIV/0!
Month | 1 | 2 | 3 | 4 | 5 | 6 | 7 | 8 | 9 | 10 | 11 | 12 | 13 | 14 | 15 | 16 | 17 | 18 | 19 | 20 | 21 | 22 | 23 | 24 | 25 | 26 | 27 | 28 | 29 | 30 | 31 | 32 | 33 | 34 | 35 | 36
Money You Invested | #DIV/0! | #DIV/0! | #DIV/0! | #DIV/0! | #DIV/0! | #DIV/0! | #DIV/0! | #DIV/0! | #DIV/0! | #DIV/0! | #DIV/0! | #DIV/0! | #DIV/0! | #DIV/0! | #DIV/0! | #DIV/0! | #DIV/0! | #DIV/0! | #DIV/0! | #DIV/0! | #DIV/0! | #DIV/0! | #DIV/0! | #DIV/0! | #DIV/0! | #DIV/0! | #DIV/0! | #DIV/0! | #DIV/0! | #DIV/0! | #DIV/0! | #DIV/0! | #DIV/0! | #DIV/0! | #DIV/0! | #DIV/0!
Money You Invested (+) | #DIV/0! | #DIV/0! | #DIV/0! | #DIV/0! | #DIV/0! | #DIV/0! | #DIV/0! | #DIV/0! | #DIV/0! | #DIV/0! | #DIV/0! | #DIV/0! | #DIV/0! | #DIV/0! | #DIV/0! | #DIV/0! | #DIV/0! | #DIV/0! | #DIV/0! | #DIV/0! | #DIV/0! | #DIV/0! | #DIV/0! | #DIV/0! | #DIV/0! | #DIV/0! | #DIV/0! | #DIV/0! | #DIV/0! | #DIV/0! | #DIV/0! | #DIV/0! | #DIV/0! | #DIV/0! | #DIV/0! | #DIV/0!
Money You Invested (-) | #DIV/0! | #DIV/0! | #DIV/0! | #DIV/0! | #DIV/0! | #DIV/0! | #DIV/0! | #DIV/0! | #DIV/0! | #DIV/0! | #DIV/0! | #DIV/0! | #DIV/0! | #DIV/0! | #DIV/0! | #DIV/0! | #DIV/0! | #DIV/0! | #DIV/0! | #DIV/0! | #DIV/0! | #DIV/0! | #DIV/0! | #DIV/0! | #DIV/0! | #DIV/0! | #DIV/0! | #DIV/0! | #DIV/0! | #DIV/0! | #DIV/0! | #DIV/0! | #DIV/0! | #DIV/0! | #DIV/0! | #DIV/0!
Revenue | 0.00 | 0.00 | 0.00 | 0.00 | 0.00 | 0.00 | 0.00 | 0.00 | 0.00 | 0.00 | 0.00 | 0.00 | 0.00 | 0.00 | 0.00 | 0.00 | 0.00 | 0.00 | 0.00 | 0.00 | 0.00 | 0.00 | 0.00 | 0.00 | 0.00 | 0.00 | 0.00 | 0.00 | 0.00 | 0.00 | 0.00 | 0.00 | 0.00 | 0.00 | 0.00 | 0.00
Variable Cost | 0.00 | 0.00 | 0.00 | 0.00 | 0.00 | 0.00 | 0.00 | 0.00 | 0.00 | 0.00 | 0.00 | 0.00 | 0.00 | 0.00 | 0.00 | 0.00 | 0.00 | 0.00 | 0.00 | 0.00 | 0.00 | 0.00 | 0.00 | 0.00 | 0.00 | 0.00 | 0.00 | 0.00 | 0.00 | 0.00 | 0.00 | 0.00 | 0.00 | 0.00 | 0.00 | 0.00
Fixed Cost | #DIV/0! | #DIV/0! | #DIV/0! | #DIV/0! | #DIV/0! | #DIV/0! | #DIV/0! | #DIV/0! | #DIV/0! | #DIV/0! | #DIV/0! | #DIV/0! | #DIV/0! | #DIV/0! | #DIV/0! | #DIV/0! | #DIV/0! | #DIV/0! | #DIV/0! | #DIV/0! | #DIV/0! | #DIV/0! | #DIV/0! | #DIV/0! | #DIV/0! | #DIV/0! | #DIV/0! | #DIV/0! | #DIV/0! | #DIV/0! | #DIV/0! | #DIV/0! | #DIV/0! | #DIV/0! | #DIV/0! | #DIV/0!
Net Profit | #DIV/0! | #DIV/0! | #DIV/0! | #DIV/0! | #DIV/0! | #DIV/0! | #DIV/0! | #DIV/0! | #DIV/0! | #DIV/0! | #DIV/0! | #DIV/0! | #DIV/0! | #DIV/0! | #DIV/0! | #DIV/0! | #DIV/0! | #DIV/0! | #DIV/0! | #DIV/0! | #DIV/0! | #DIV/0! | #DIV/0! | #DIV/0! | #DIV/0! | #DIV/0! | #DIV/0! | #DIV/0! | #DIV/0! | #DIV/0! | #DIV/0! | #DIV/0! | #DIV/0! | #DIV/0! | #DIV/0! | #DIV/0!

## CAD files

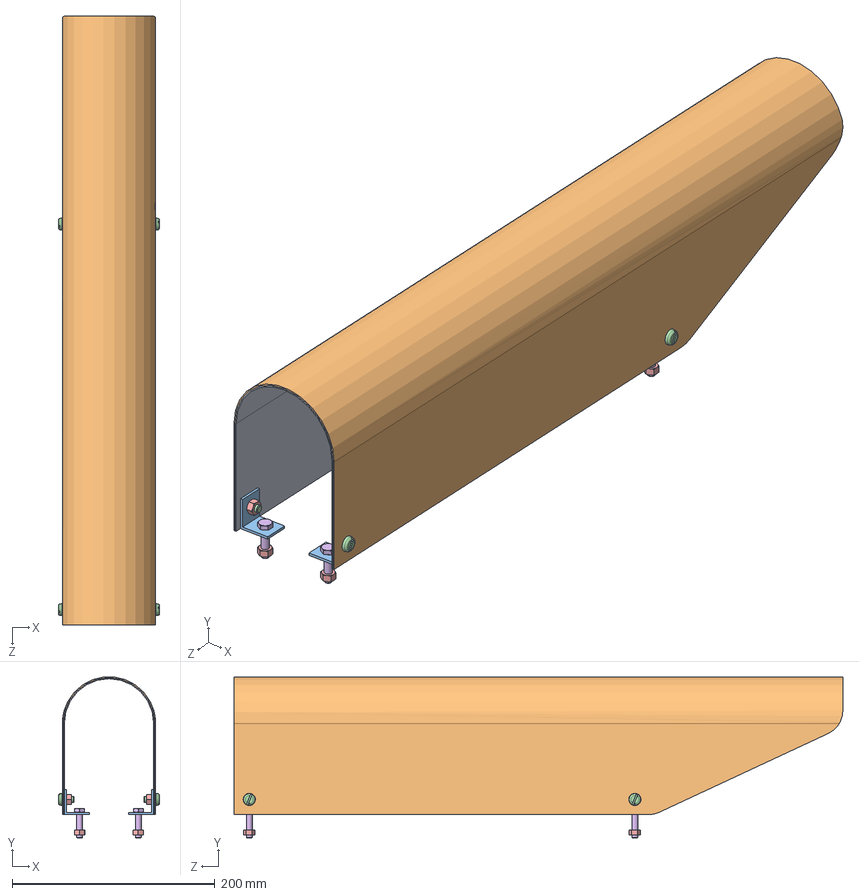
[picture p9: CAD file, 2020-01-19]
3. Build the machine/Upgrades/Heat Protection/1-3D CAD/EXTPRO-V1 3000.06-A Heat Protection.SLDASM
99.8 x 158.7 x 600.0 mm
Heat isolant
Heat protection
Square x 4
Screw M6X12 x 4
Nut HM6 x 8
Screw M6X25 x 4

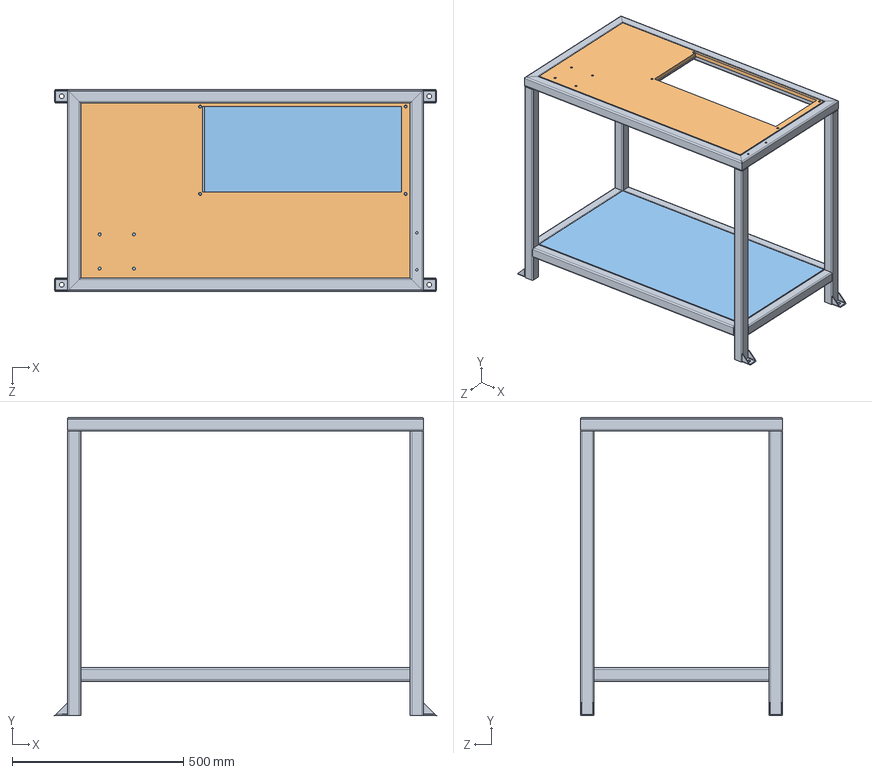
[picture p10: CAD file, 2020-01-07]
3. Build the machine/Extrusion-Pro-Files/1-3D CAD/Extruder Solidworks CAD/EXTPRO-V1 3000.00-A Frame.SLDASM
1114.8 x 870.0 x 590.0 mm
EXTPRO-V1 3000.01-A Main frame
EXTPRO-V1 3000.02-A Top shelf
EXTPRO-V1 3000.03-A Bottom shelf

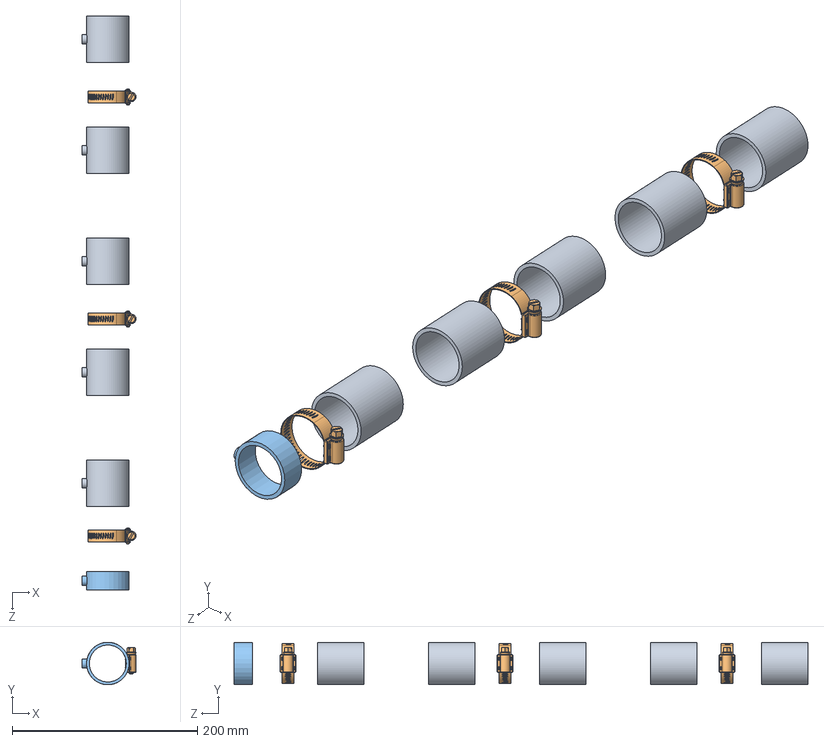
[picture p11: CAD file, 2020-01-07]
3. Build the machine/Extrusion-Pro-Files/1-3D CAD/Extruder Solidworks CAD/EXTPRO-V1 1300.00-A Extruder electronics.SLDASM
58.5 x 45.9 x 620.5 mm
EXT-V4 1300.01-A Heating element 40x50 350W x 5
EXT-V4 1300.02-A Thermocouple x 3
EXT-V4 1300.03-A Heating element 40x20 150W

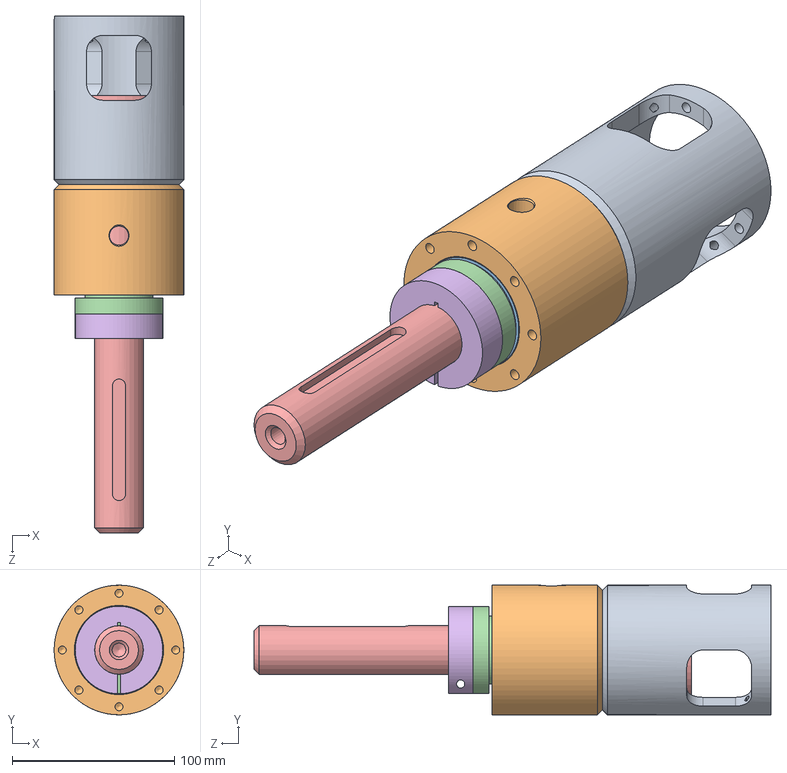
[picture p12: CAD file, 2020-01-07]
3. Build the machine/Extrusion-Pro-Files/1-3D CAD/Extruder Solidworks CAD/EXTPRO-V1 1120.00-A Bearing Body _ Shaft.SLDASM
80.0 x 80.0 x 319.0 mm
EXTPRO-V1 1121.01-A Transition Piece
EXTPRO-V1 1121.02-A Bearing body
EXTPRO-V1 02 Bearing seal-din3760-as_42x55x8-fkm x 2
EXTPRO-V1 1120.01-A Seal bearing spacer
EXTPRO-V1 1120.02-A Coupling Shaft
EXTPRO-V1 03 Shaft Clamp

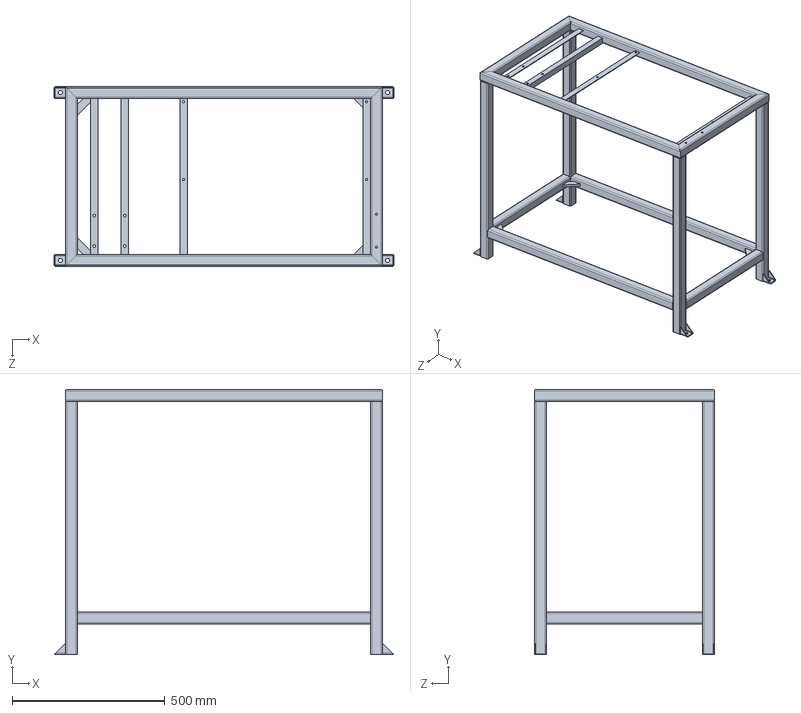
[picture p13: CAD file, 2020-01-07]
3. Build the machine/Extrusion-Pro-Files/1-3D CAD/Extruder Solidworks CAD/EXTPRO-V1 3000.01-A Main frame.SLDPRT
1114.8 x 870.0 x 590.0 mm

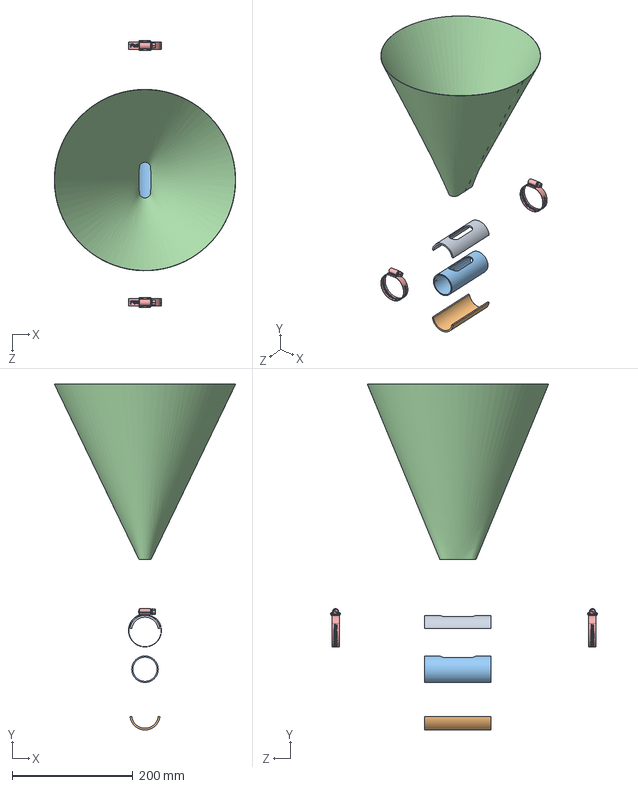
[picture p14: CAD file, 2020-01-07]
3. Build the machine/Extrusion-Pro-Files/1-3D CAD/Extruder Solidworks CAD/EXTPRO-V1 1200.00-A Cone Hopper.SLDASM
300.0 x 572.2 x 441.7 mm
EXTPRO-V1 1200.01-A Top
EXTPRO-V1 1200.02-A Bottom
EXTPRO-V1 1200.03-A Insulation
EXTPRO-V1 1200.04-A Cone
EXTPRO-V1 10 Clamp x 2

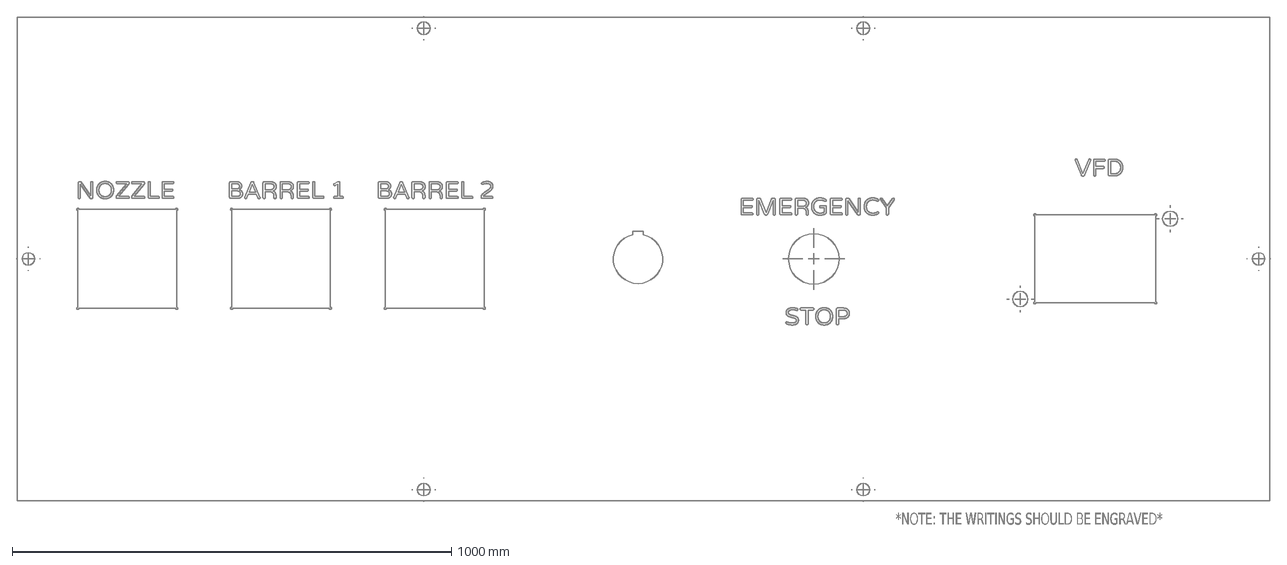
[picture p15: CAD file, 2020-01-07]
3. Build the machine/Extrusion-Pro-Files/2-Laser cut files/DXF/Electronics box (1mm_CarbonSteel)/EXTPRO-V1 2100.02-A Front - QTY_1.DXF
*NOTE: THE WRITINGS SHOULD BE ENGRAVED*

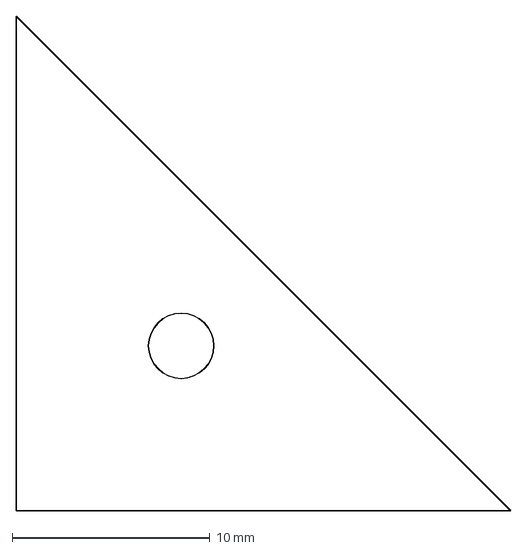
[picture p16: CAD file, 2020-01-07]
3. Build the machine/Extrusion-Pro-Files/2-Laser cut files/DXF/Electronics box (6mm_CarbonSteel)/EXTPRO-V1 2100.06-A Cover attachment - QTY_4.DXF
25.0 x 25.0 mm

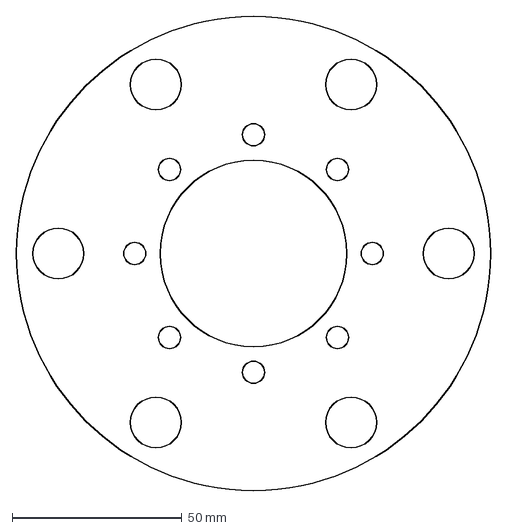
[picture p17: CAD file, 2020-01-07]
3. Build the machine/Extrusion-Pro-Files/2-Laser cut files/DXF/Flanges (8mm_CarbonSteel)/EXTPRO-V1 1110.02-A Flange 1 - QTY_1.DXF
139.7 x 139.7 mm

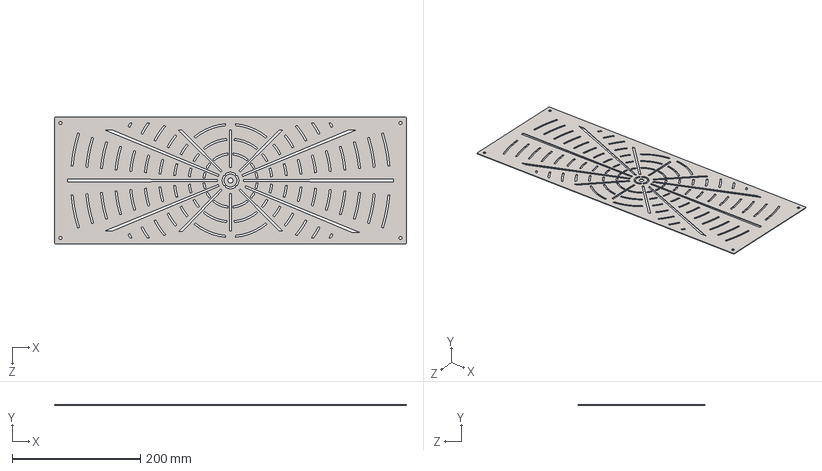
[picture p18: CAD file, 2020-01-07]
3. Build the machine/Extrusion-Pro-Files/2-Laser cut files/STEP/Electronics box (CarbonSteel)/EXTPRO-V1 2100.01-A Cover - QTY_1.STEP
550.0 x 1.00 x 198.0 mm

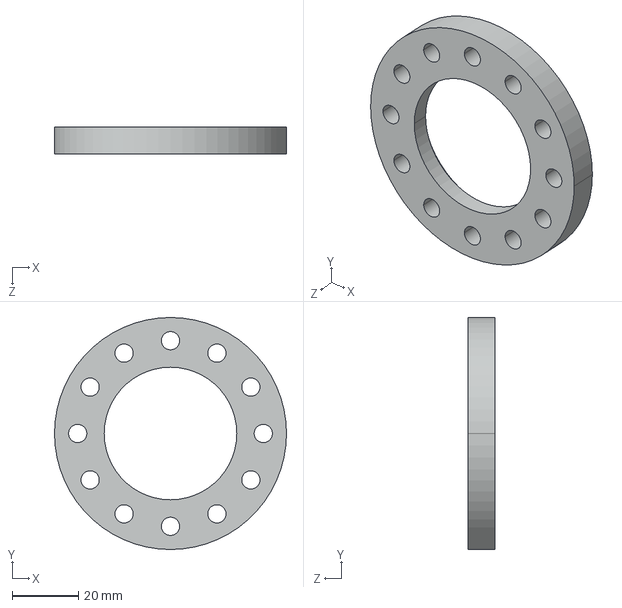
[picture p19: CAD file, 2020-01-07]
3. Build the machine/Extrusion-Pro-Files/2-Laser cut files/STEP/Flanges (CarbonSteel)/EXTPRO-V1 1130.03-A Barrel flange 2 - QTY_1.STEP
70.0 x 70.0 x 8.00 mm

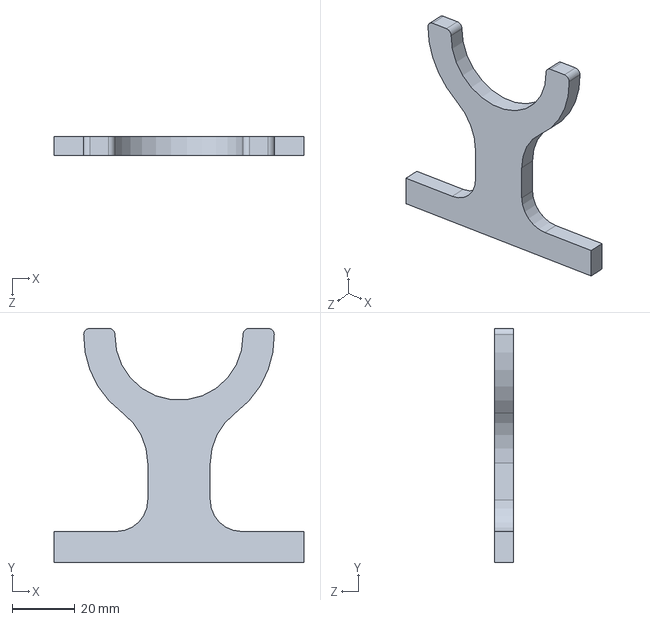
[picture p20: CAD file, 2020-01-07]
3. Build the machine/Upgrades/Barrel Support/1-3D CAD/EXTPRO-V1 3000.04-A Barrel support.SLDPRT
80.0 x 75.0 x 6.00 mm

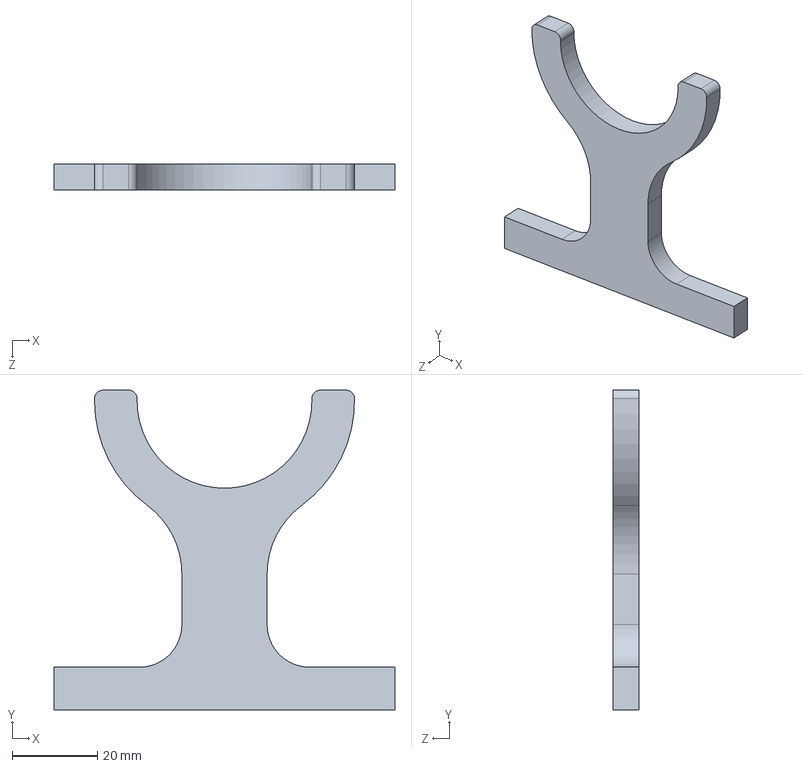
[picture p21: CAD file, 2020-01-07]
3. Build the machine/Upgrades/Barrel Support/2-Laser cut files/STEP (6mm_CarbonSteel)/EXTPRO-V1 3000.04-A Barrel support - QTY_1.STEP
80.0 x 75.0 x 6.00 mm

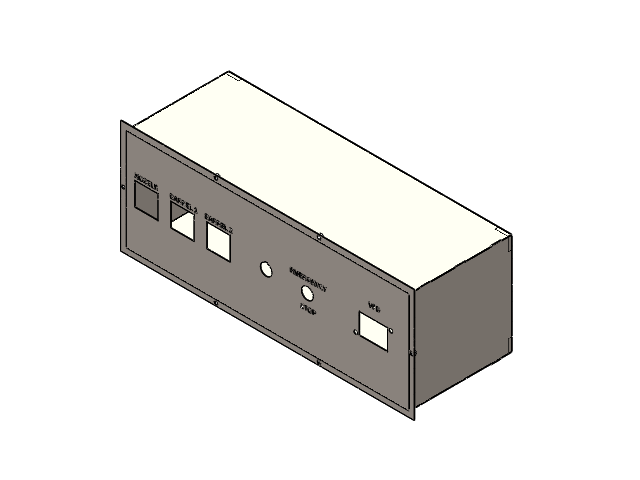
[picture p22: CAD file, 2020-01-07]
3. Build the machine/Extrusion-Pro-Files/1-3D CAD/Extruder Solidworks CAD/EXTPRO-V1 2100.00-A Electronics box assembly.SLDASM
EXTPRO-V1 2100.01-A Cover
EXTPRO-V1 2100.02-A Front
EXTPRO-V1 2100.03-A Side 2
EXTPRO-V1 2100.04-A Side 1
EXTPRO-V1 2100.05-A Side 3 x 2
EXTPRO-V1 2100.06-A Cover attachment x 4
EXTPRO-V1 14 M5 Nut x 6
EXTPRO-V1 15 M6x10 Socket head screw x 4

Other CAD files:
3. Build the machine/Extrusion-Pro-Files/1-3D CAD/Extruder Solidworks CAD/EXTPRO-V1 1140.00-A Barrel.SLDASM
3. Build the machine/Extrusion-Pro-Files/1-3D CAD/Extruder Solidworks CAD/EXTPRO-V1 1110.00-A Gearbox flange.sldasm
3. Build the machine/Extrusion-Pro-Files/1-3D CAD/Extruder Solidworks CAD/EXTPRO-V1 1121.00-A Bearing body.SLDASM
3. Build the machine/Extrusion-Pro-Files/1-3D CAD/Extruder Solidworks CAD/EXTPRO-V1 1130.00-A Barrel inlet.SLDASM
3. Build the machine/Extrusion-Pro-Files/1-3D CAD/Extruder Solidworks CAD/EXTPRO-V1 0000.00-A Main assembly.SLDDRW
3. Build the machine/Extrusion-Pro-Files/1-3D CAD/Extruder Solidworks CAD/EXTPRO-V1 01 Motor BAZ39-LE100ZLSB4P.SLDPRT
3. Build the machine/Extrusion-Pro-Files/1-3D CAD/Extruder Solidworks CAD/EXTPRO-V1 02 Bearing seal-din3760-as_42x55x8-fkm.SLDPRT
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

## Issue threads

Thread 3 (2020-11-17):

organise CAD files in assembly zip for onshape import

Boorhin, 2020-11-17:
to import the solidwork assembly into onshape, the files need to be zipped together and be organised by assembly.
Currently looking at  the extruder pro and I am not sure which assembly corresponds to what. So cannot import the assembly, just the individual parts

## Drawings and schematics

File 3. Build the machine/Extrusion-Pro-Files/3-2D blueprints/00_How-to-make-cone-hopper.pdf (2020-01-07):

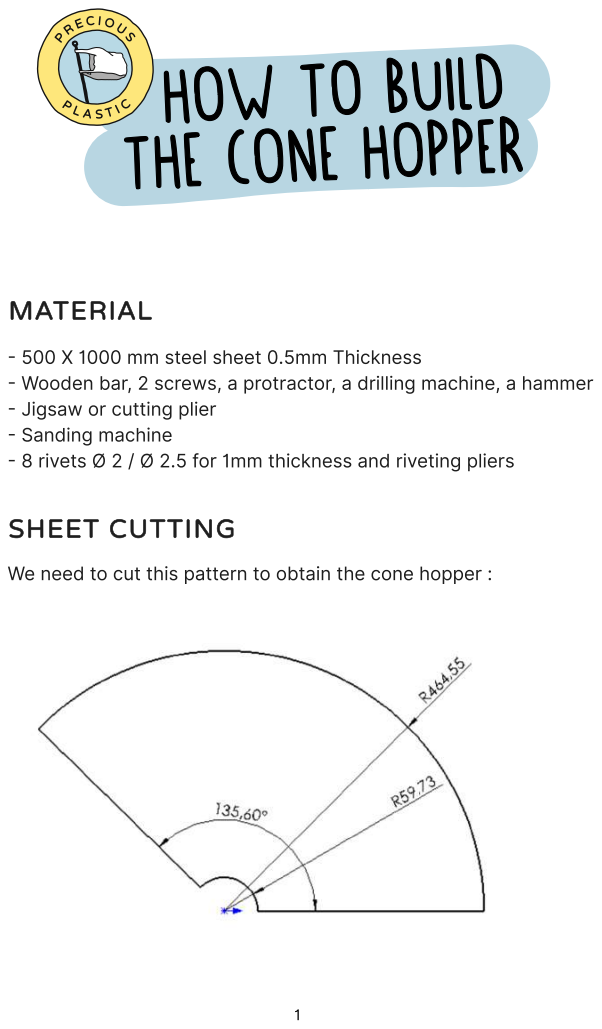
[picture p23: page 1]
material; Sheet cutting

How to build

the cone hopper

- 500 X 1000 mm steel sheet 0.5mm Thickness
- Wooden bar, 2 screws, a protractor, a drilling machine, a hammer
- Jigsaw or cutting plier
- Sanding machine
- 8 rivets Ø 2 / Ø 2.5 for 1mm thickness and riveting pliers

We need to cut this pattern to obtain the cone hopper :

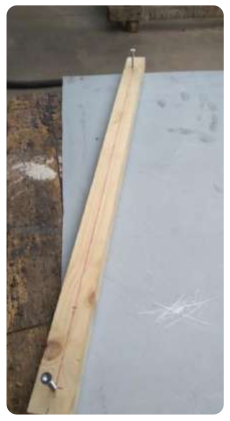
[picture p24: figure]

The easiest way to mark and cut it is to use a wooden bar as a compass. You can mark the two diameter using two screw.

1) Tighten the two screws in the center of

the wooden bar at a distance of 464.5 mm from each other
2) Hammer the first screw for the center

of the cone at the extremity of the sheet
3) Rotate the wooden bar to mark the

plate with the tip of the second screw.
4) Repeat for the inner diameter of 59.7

mm.
5) Use a protractor to determine the angle

of 135.6°.
6) Use a Jigsaw or cutting plier to cut the

sheet.
7) Use your sanding machine for finishing

touch and polish it to clear imperfections.

Before bending the cone :
- Draw 2 lines with a pencil 10 mm from the edge on both side
- Then drill ONE side of the sheet according to the drawing below (8 holes / the drilling diameter is determined by the diameter of your rivets.)

## Sheet bending

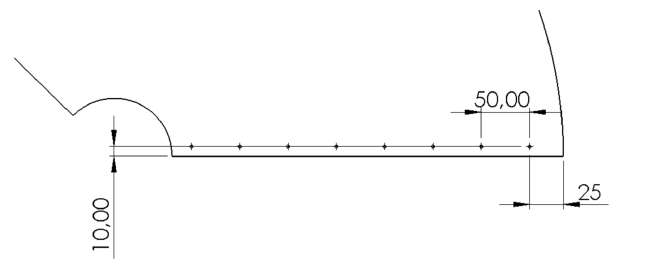
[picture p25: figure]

Caution when welding, the cone is very thin.

Then you can start to bend manually to make the shape of the cone and get help with a conical shaped object and roll the sheet.

When you have reached a sufficient form, you can overlap both parts, be careful to overlap the 2 lines located at 10 mm from the edge.
Start to make the first hole on the top of the cone to drill the bottom sheet. You can put your first rivet.
Then drill the second hole while maintaining the overlap of the lines. Put the second rivet and so on.
Finally the last folding is done after finishing the cone and putting the rivets. The folding consists in completing the hollow shape of the EXTPRO-V1 1200.01-A Top part
This folding is done manually using the barrel inlet part (EXTPRO-V1 1200.01-A Top) and copy the same hollow shape in

order to weld the two parts more easily.

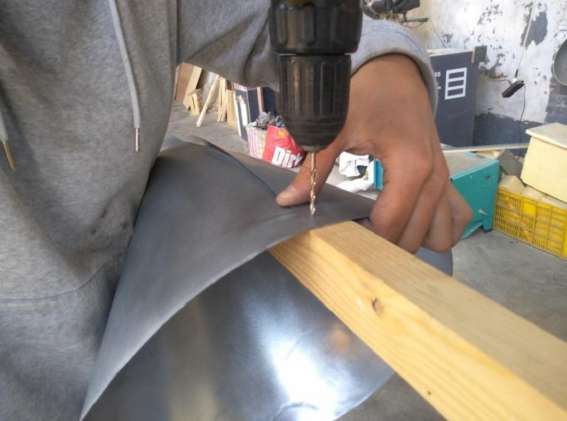
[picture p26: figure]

## You can change the dimension of your cone hopper (length B and C) as your convenience :

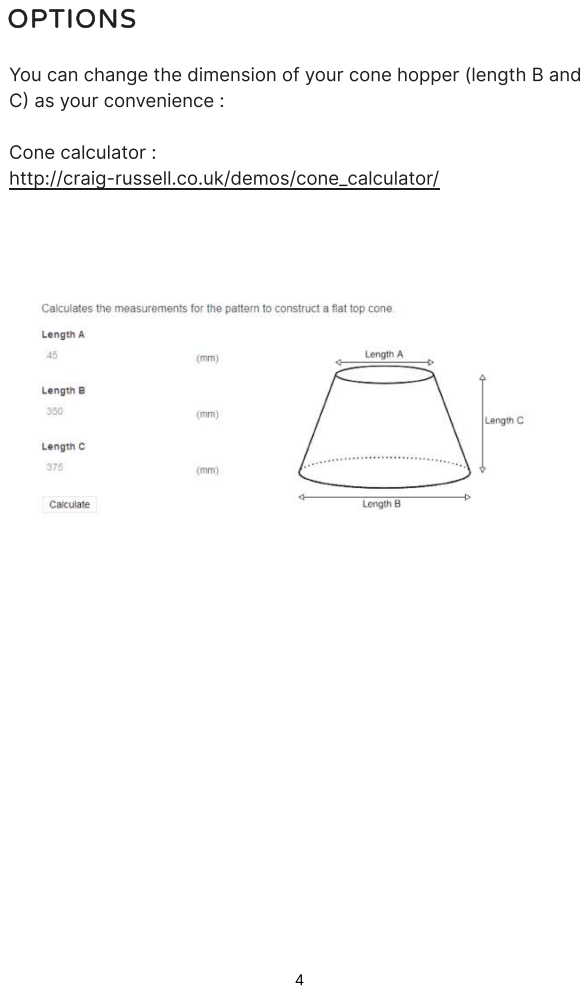
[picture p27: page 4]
OPTIONS

Cone calculator :
http://craig-russell.co.uk/demos/cone_calculator/

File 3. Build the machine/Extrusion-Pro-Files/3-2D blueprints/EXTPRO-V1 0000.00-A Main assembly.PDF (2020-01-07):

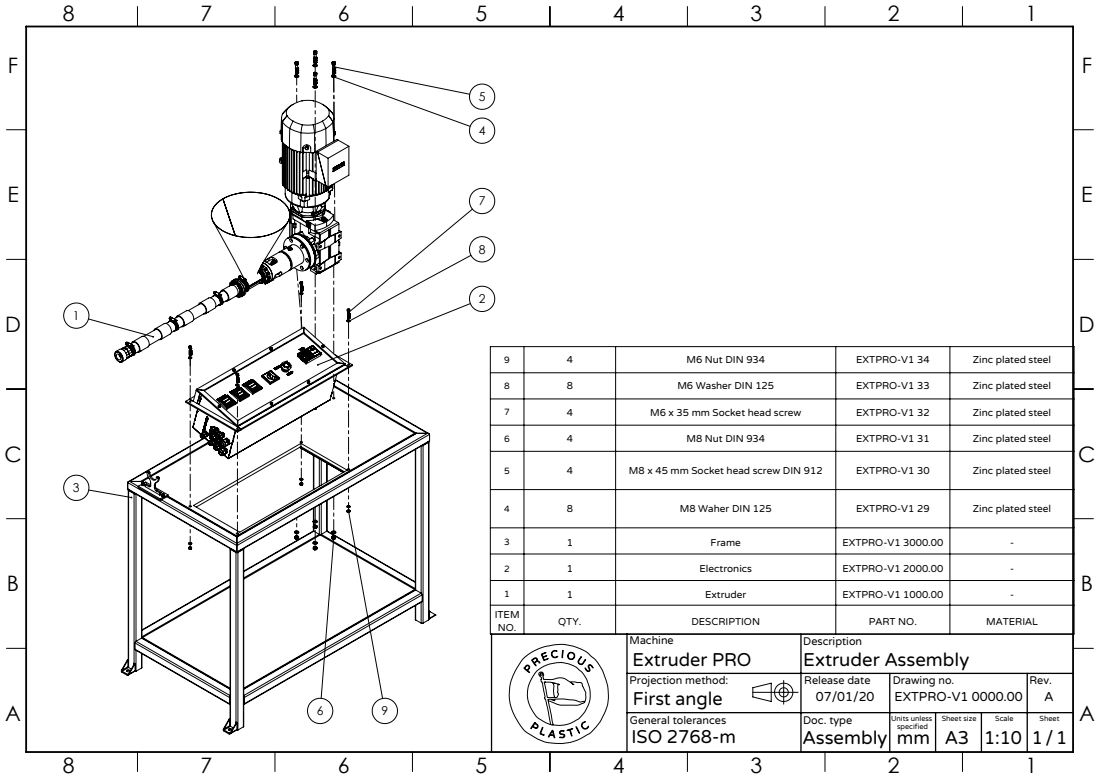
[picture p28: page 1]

9 | 4 | M6 Nut DIN 934 | EXTPRO-V1 34 | Zinc plated steel

8 | 8 | M6 Washer DIN 125 | EXTPRO-V1 33 | Zinc plated steel

7 | 4 | M6 x 35 mm Socket head screw | EXTPRO-V1 32 | Zinc plated steel

6 | 4 | M8 Nut DIN 934 | EXTPRO-V1 31 | Zinc plated steel

5 | 4 | M8 x 45 mm Socket head screw DIN 912 | EXTPRO-V1 30 | Zinc plated steel

4 | 8 | M8 Waher DIN 125 | EXTPRO-V1 29 | Zinc plated steel

3 | 1 | Frame | EXTPRO-V1 3000.00 | -

2 | 1 | Electronics | EXTPRO-V1 2000.00 | -

1 | 1 | Extruder | EXTPRO-V1 1000.00 | -
ITEM NO. | QTY. | DESCRIPTION | PART NO. | MATERIAL

Machine Extruder PRO | Description Extruder Assembly
Projection method: First angle | Release date 07/01/20 | Drawing no. EXTPRO-V1 0000.00 | Rev. A
General tolerances ISO 2768-m | Doc. type Assembly | Units unless specified mm | Sheet size A3 | Scale 1:10 | Sheet 1 1 /

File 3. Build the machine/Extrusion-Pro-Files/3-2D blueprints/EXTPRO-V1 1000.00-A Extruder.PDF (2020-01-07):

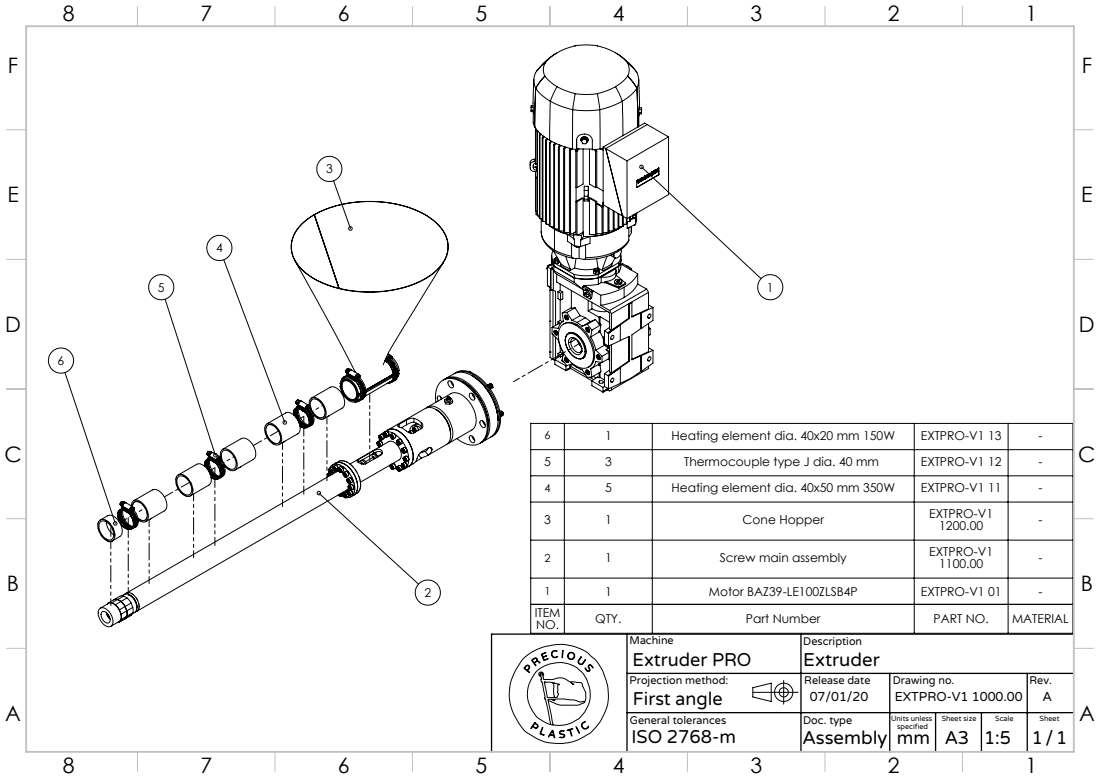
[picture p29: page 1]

6 | 1 | Heating element dia. 40x20 mm 150W | EXTPRO-V1 13 | -
5 | 3 | Thermocouple type J dia. 40 mm | EXTPRO-V1 12 | -
4 | 5 | Heating element dia. 40x50 mm 350W | EXTPRO-V1 11 | -
3 | 1 | Cone Hopper | EXTPRO-V1 1200.00 | -

2 | 1 | Screw main assembly | EXTPRO-V1 1100.00 | -

1 | 1 | Motor BAZ39-LE100ZLSB4P | EXTPRO-V1 01 | -
ITEM NO. | QTY. | Part Number | PART NO. | MATERIAL

Machine Extruder PRO | Description Extruder
Projection method: First angle | Release date 07/01/20 | Drawing no. EXTPRO-V1 1000.00 | Rev. A
General tolerances ISO 2768-m | Doc. type Assembly | Units unless specified mm | Sheet size A3 | Scale 1:5 | Sheet 1 1 /

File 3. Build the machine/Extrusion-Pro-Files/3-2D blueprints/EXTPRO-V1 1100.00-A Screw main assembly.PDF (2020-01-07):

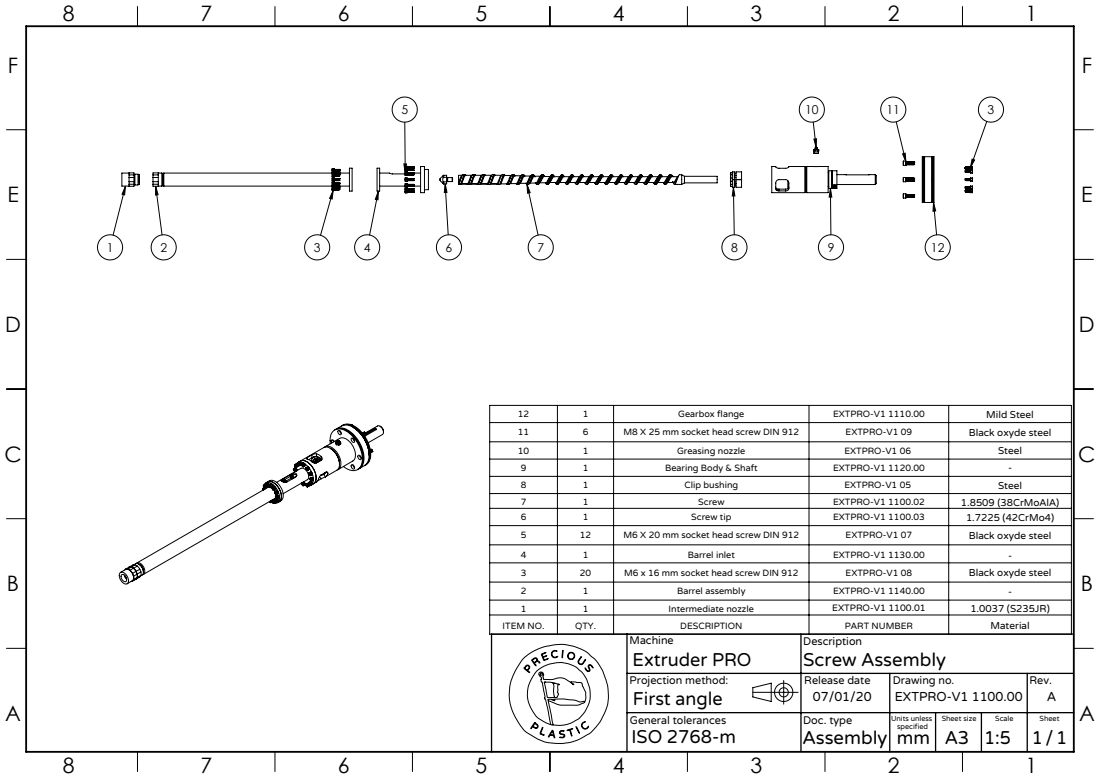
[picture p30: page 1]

12 | 1 | Gearbox flange | EXTPRO-V1 1110.00 | Mild Steel
11 | 6 | M8 X 25 mm socket head screw DIN 912 | EXTPRO-V1 09 | Black oxyde steel
10 | 1 | Greasing nozzle | EXTPRO-V1 06 | Steel
9 | 1 | Bearing Body & Shaft | EXTPRO-V1 1120.00 | -
8 | 1 | Clip bushing | EXTPRO-V1 05 | Steel
7 | 1 | Screw | EXTPRO-V1 1100.02 | 1.8509 (38CrMoAlA)
6 | 1 | Screw tip | EXTPRO-V1 1100.03 | 1.7225 (42CrMo4)
5 | 12 | M6 X 20 mm socket head screw DIN 912 | EXTPRO-V1 07 | Black oxyde steel
4 | 1 | Barrel inlet | EXTPRO-V1 1130.00 | -
3 | 20 | M6 x 16 mm socket head screw DIN 912 | EXTPRO-V1 08 | Black oxyde steel
2 | 1 | Barrel assembly | EXTPRO-V1 1140.00 | -
1 | 1 | Intermediate nozzle | EXTPRO-V1 1100.01 | 1.0037 (S235JR)
ITEM NO. | QTY. | DESCRIPTION | PART NUMBER | Material

Machine Extruder PRO | Description Screw Assembly
Projection method: First angle | Release date 07/01/20 | Drawing no. EXTPRO-V1 1100.00 | Rev. A
General tolerances ISO 2768-m | Doc. type Assembly | Units unless specified mm | Sheet size A3 | Scale 1:5 | Sheet 1 1 /

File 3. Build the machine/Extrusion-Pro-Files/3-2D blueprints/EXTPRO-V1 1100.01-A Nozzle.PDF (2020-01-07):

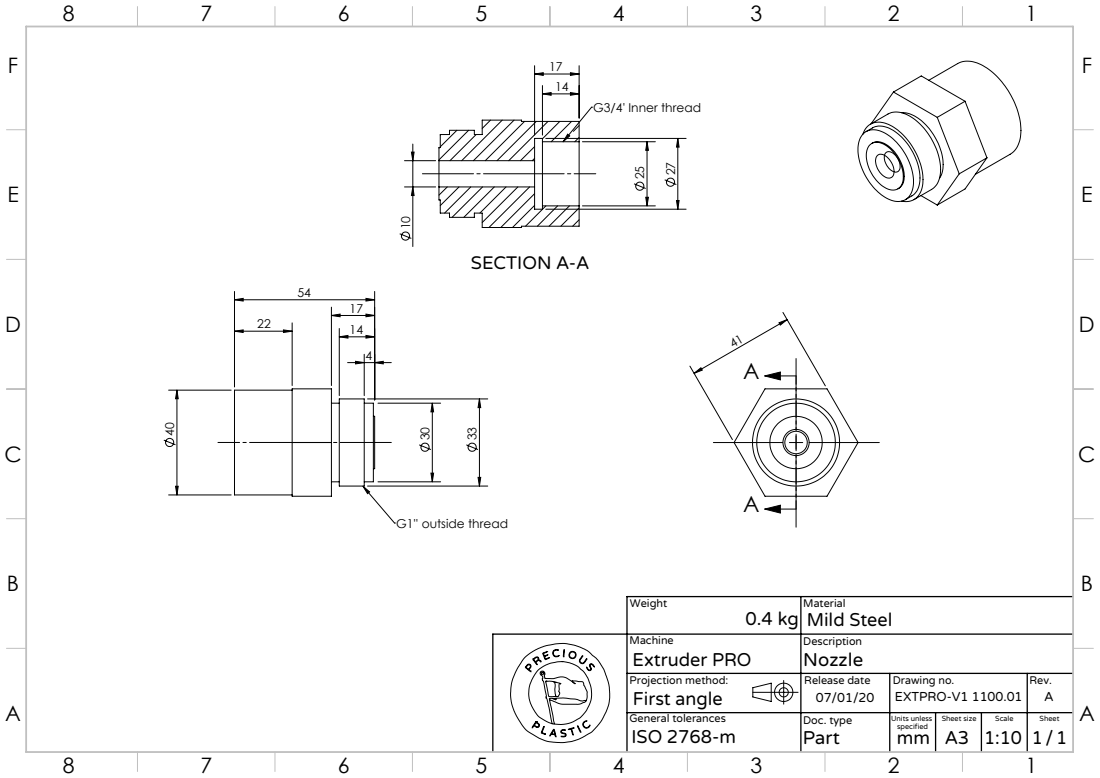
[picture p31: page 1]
G1'' outside thread 10; SECTION A-A; G3/4' Inner thread

Weight 0.4 kg | Material Mild Steel

Machine Extruder PRO | Description Nozzle
Projection method: First angle | Release date 07/01/20 | Drawing no. EXTPRO-V1 1100.01 | Rev. A
General tolerances ISO 2768-m | Doc. type Part | Units unless specified mm | Sheet size A3 | Scale 1:10 | Sheet 1 1 /

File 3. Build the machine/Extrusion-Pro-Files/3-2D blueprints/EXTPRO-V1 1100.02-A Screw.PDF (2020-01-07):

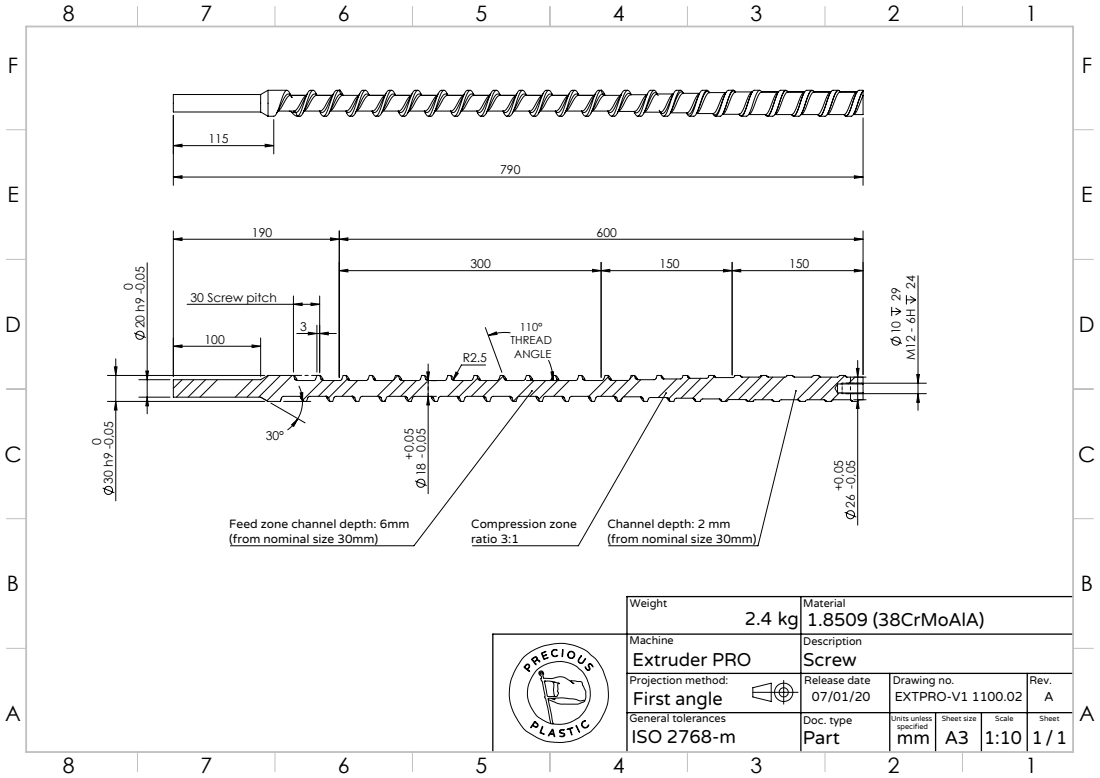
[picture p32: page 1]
30 Screw pitch; Compression zone ratio 3:1

Feed zone channel depth: 6mm
(from nominal size 30mm)

Channel depth: 2 mm

Weight 2.4 kg | Material 1.8509 (38CrMoAlA)

Machine Extruder PRO | Description Screw
Projection method: First angle | Release date 07/01/20 | Drawing no. EXTPRO-V1 1100.02 | Rev. A
General tolerances ISO 2768-m | Doc. type Part | Units unless specified mm | Sheet size A3 | Scale 1:10 | Sheet 1 1 /

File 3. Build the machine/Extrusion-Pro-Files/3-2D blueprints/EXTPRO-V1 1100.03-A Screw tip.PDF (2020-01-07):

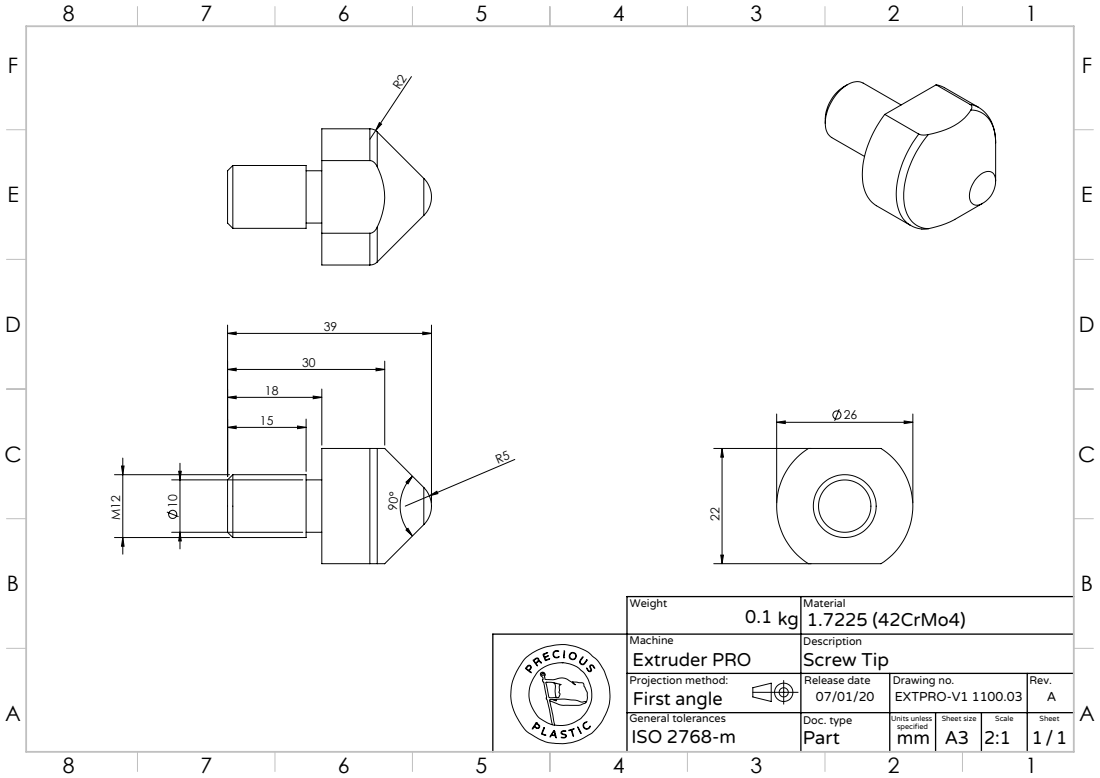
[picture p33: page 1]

Weight 0.1 kg | Material 1.7225 (42CrMo4)

Machine Extruder PRO | Description Screw Tip
Projection method: First angle | Release date 07/01/20 | Drawing no. EXTPRO-V1 1100.03 | Rev. A
General tolerances ISO 2768-m | Doc. type Part | Units unless specified mm | Sheet size A3 | Scale 2:1 | Sheet 1 1 /

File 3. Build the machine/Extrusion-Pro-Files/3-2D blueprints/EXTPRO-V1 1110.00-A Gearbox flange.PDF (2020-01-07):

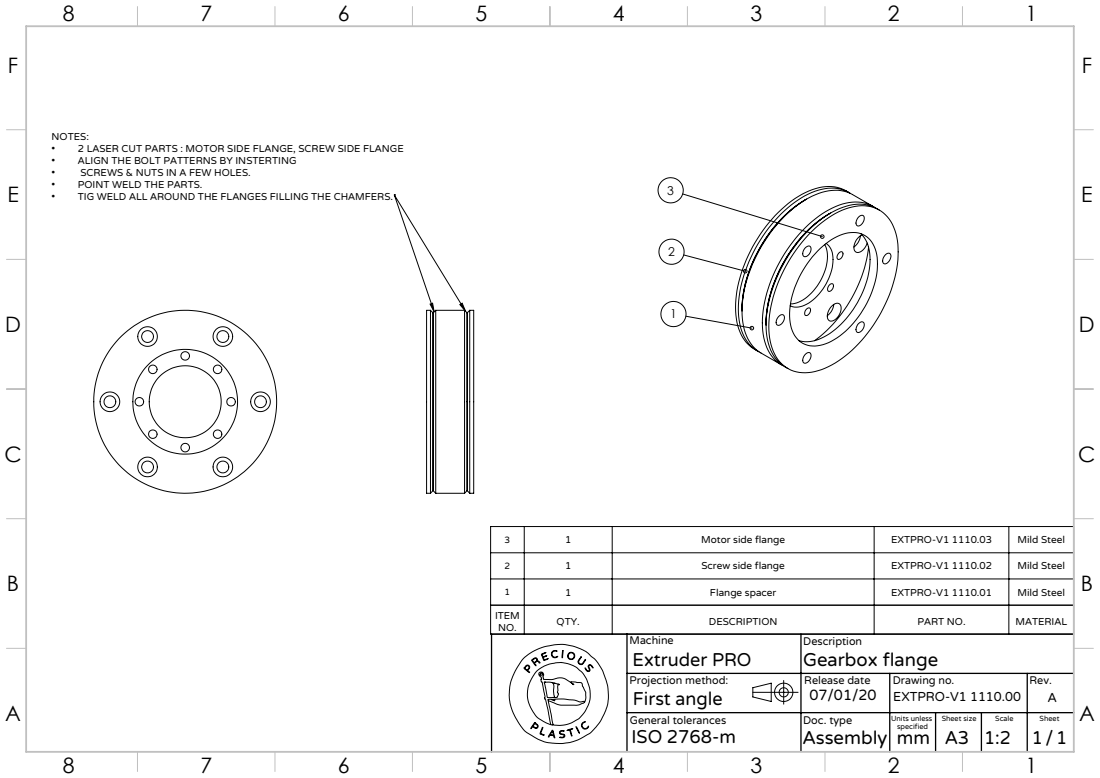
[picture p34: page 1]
First angle; Projection method:

NOTES:
• 2 LASER CUT PARTS : MOTOR SIDE FLANGE, SCREW SIDE FLANGE
• ALIGN THE BOLT PATTERNS BY INSTERTING
• SCREWS & NUTS IN A FEW HOLES.
• POINT WELD THE PARTS.

• TIG WELD ALL AROUND THE FLANGES FILLING THE CHAMFERS.

3 | 1 | Motor side flange | EXTPRO-V1 1110.03 | Mild Steel

2 | 1 | Screw side flange | EXTPRO-V1 1110.02 | Mild Steel

1 | 1 | Flange spacer | EXTPRO-V1 1110.01 | Mild Steel

ITEM NO. | QTY. | DESCRIPTION | PART NO. | MATERIAL

Machine Extruder PRO | Description Gearbox flange

Release date 07/01/20 | Drawing no. EXTPRO-V1 1110.00 | Rev. A

General tolerances ISO 2768-m | Doc. type Assembly | Units unless specified mm | Sheet size A3 | Scale 1:2 | Sheet 1 1 /

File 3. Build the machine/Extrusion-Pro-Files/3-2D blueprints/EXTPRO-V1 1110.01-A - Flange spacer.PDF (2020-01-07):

WELDING CHAMFER

Weight 0.5 kg | Material Mild Steel

Machine Extruder PRO | Description Motor side flange
Projection method: First angle | Release date 07/01/20 | Drawing no. EXTPRO-V1 1110.01 | Rev. A
General tolerances ISO 2768-m | Doc. type Part | Units unless specified mm | Sheet size A3 | Scale 1:1 | Sheet 1 1 /

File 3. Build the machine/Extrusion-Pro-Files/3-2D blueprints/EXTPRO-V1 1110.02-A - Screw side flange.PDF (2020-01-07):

SECTION A-A

Stock material: laser cut plate 8mm S235JR

Weight 0.6 kg | Material Mild Steel

Machine Extruder PRO | Description Screw side flange
Projection method: First angle | Release date 07/01/20 | Drawing no. EXTPRO-V1 1110.02 | Rev. A
General tolerances ISO 2768-m | Doc. type Part | Units unless specified mm | Sheet size A3 | Scale 1:10 | Sheet 1 1 /

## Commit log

2020-01-07 starterkit - extrusion
    [Adjustmable mould support surface.IGS, Adjustmable mould support surface.STEP, Beam mould hanger.STEP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]
2020-01-19 Update Extrusion files
    [EXTPRO-V1 3000.06-A Heat Protection.SLDASM]
2020-01-19 Update Screw Price
    [Extruder BOM.xlsx]
